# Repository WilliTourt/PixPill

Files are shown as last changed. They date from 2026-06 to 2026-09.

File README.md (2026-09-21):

# 💊 PixPill

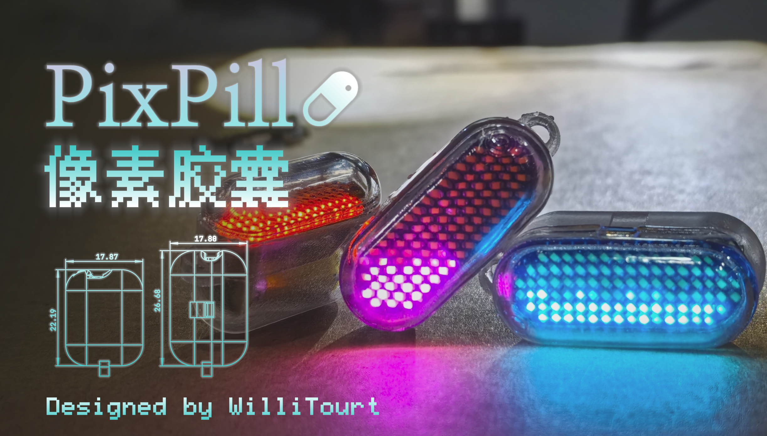
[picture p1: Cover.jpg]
Cover


> A pill-sized LED trinket — with sand and liquid flowing inside. Shake it, tilt it, watch it flow.

> [ENGLISH](README.md) | [中文](README-zh-CN.md)

**PixPill** is a tiny glowing gadget barely larger than a real pill capsule. On a 4-layer HDI micro PCB, it packs an STM32C011 MCU, a BMA530 accelerometer, an IS31FL3736 LED matrix driver, 96× micro LEDs, and an nPM1100 PMIC. The firmware runs physics-based particle simulations — tilt it and sand pours, liquid flows.

Bilibili video link：[Click here](https://www.bilibili.com/video/BV1YWhq6gEwE)

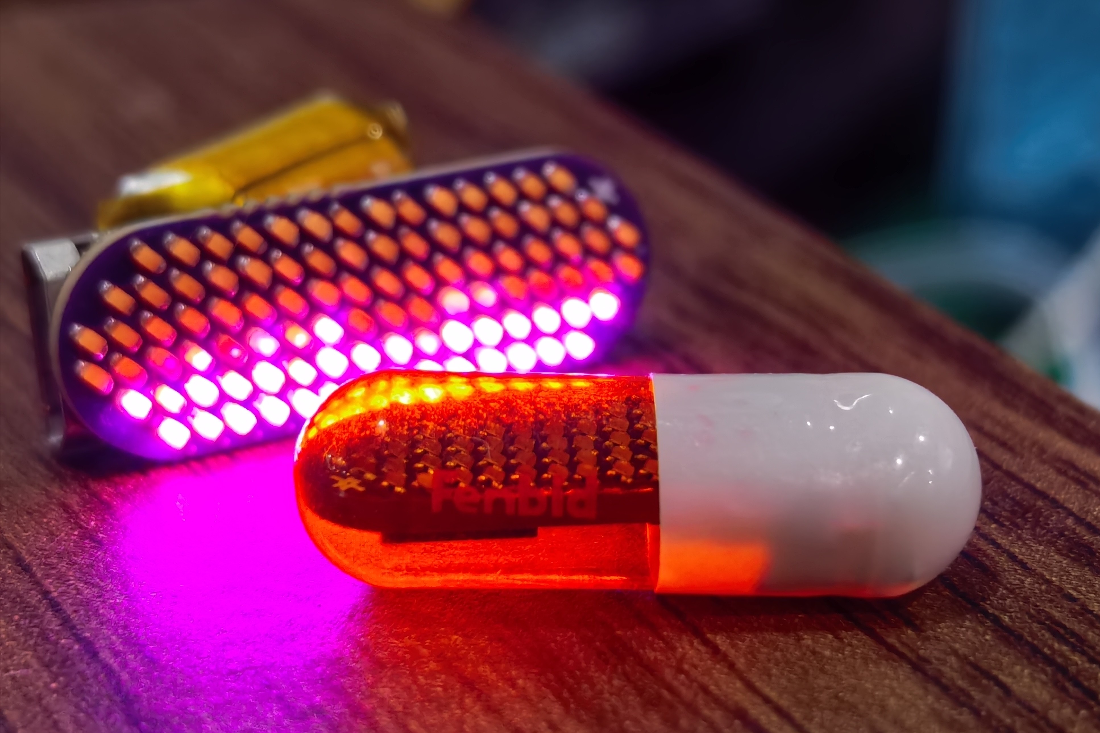
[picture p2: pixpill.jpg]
PixPill in Fenbid Capsule


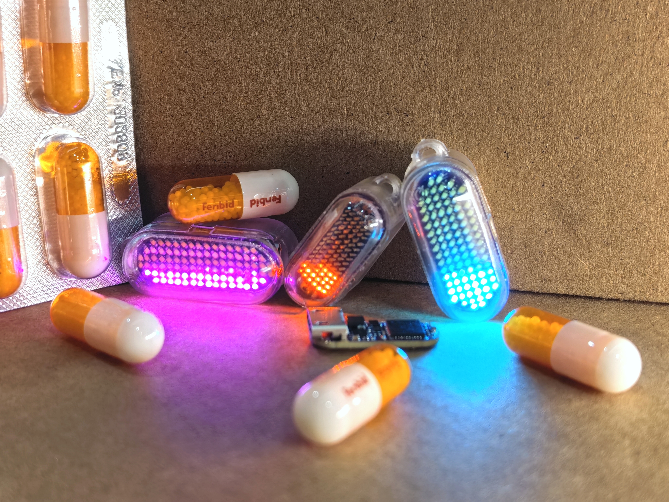
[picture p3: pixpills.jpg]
PixPills


Its tiny PCB dimensions (23.9×8.6 mm / 19.5×6.9 mm) are deliberately aligned with standardized size 000 (26.1×8.5 mm) and size 1 (19.4×6.9 mm) pill capsules.

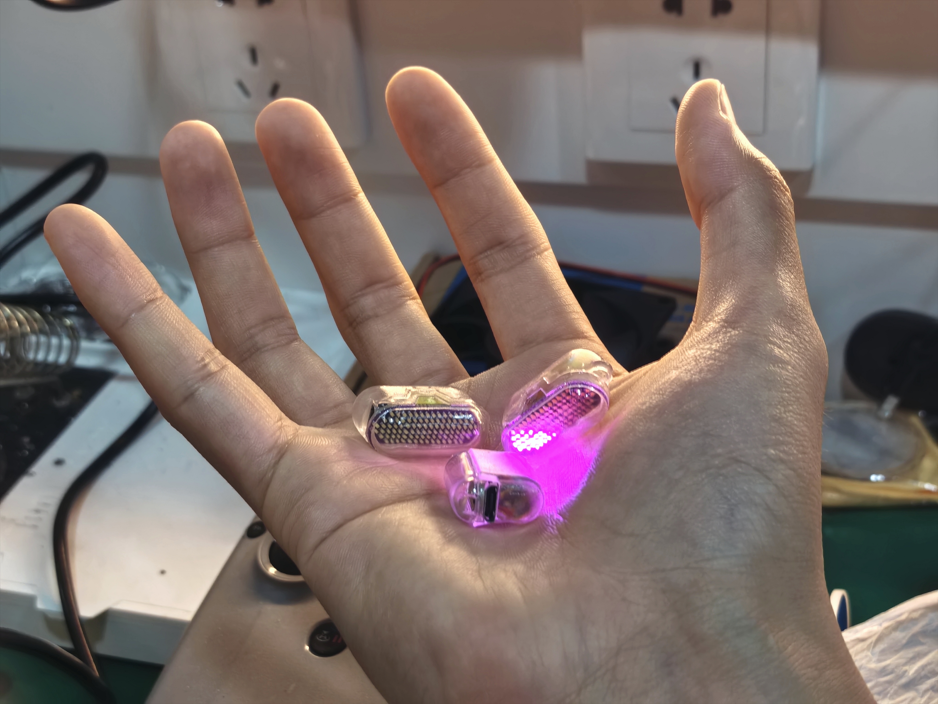
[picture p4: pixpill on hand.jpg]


For detailed hardware design and 3D-related information, see [Hardware Design.md](Hardware/Hardware%20Design.md). For software details, see [Software Design.md](Software/Software%20Design.md).

---

## Features

- **「Tiny」** — PCB as narrow as 6.9 mm in diameter; fits inside a real pill capsule
- **Two physics modes** — Sand (granular, stacks naturally) and Liquid (SPH-inspired fluid with density pressure)
- **Gesture control** — Shake up-down-up-down rapidly to toggle between sand and liquid modes
- **Auto sleep** — Enters nPM1100 ship mode (shutdown) after 22 seconds of stillness to preserve battery
- **USB charging** — microUSB for charging
- **Fault detection** — nPM1100 ERR pin triggers LED array blinking alarm, pausing normal operation
- **Animated transitions** — Boot, shutdown, charging, and error states each have unique LED animations

---

## Hardware

| Component | Part | Notes |
|---|---|---|
| **MCU** | STM32C011D6Y6TR | Cortex-M0+ @ 48 MHz, WLCSP12 (1.7×1.42×0.6 mm, 0.35 mm pitch) |
| **IMU** | BMA530 | 3-axis accelerometer, I²C, WLCSP6 (1.2×0.8×0.55 mm³) |
| **LED Driver** | IS31FL3736 | 12×8 LED matrix controller, I²C paged register access, per-LED 8-bit PWM, 5×5 QFN |
| **LEDs** | 96× 0402 (000#) / 90× 0201 (1#) | Arranged in a pill-shaped layout |
| **PMIC** | nPM1100 | Li-Po charger, max 400 mA LDO, with ship mode |
| **Battery** | 08120 3.7V Li-Po | Charged via microUSB |
| **PCB** | 4-layer 1st-order HDI | 23.9×8.6 mm / 19.5×6.9 mm |

---

## Simulation

### Sand Mode

- Based on a cellular-automaton classic falling-sand algorithm
- 8 gravity directions, conforming to the natural angle of repose of sand
- Particles stack naturally along gravity; tilt spills them
- Frame rate adapts to tilt angle

### Liquid Mode

- SPH-inspired implementation: gravity + density field pressure + inter-particle repulsion + velocity damping
- Finer sub-step integration per frame
- Inter-particle collision detection
- 18×6 density grid mapped to the 96-LED pill-shaped layout
- Surface tension available but currently disabled

---

## Firmware Architecture

```
main.c                   ← STM32CubeMX HAL init → cpp_main() main loop
Components/
├── Src/
│   ├── cpp_main.cpp     ← state machine, gesture detection, main loop
│   ├── bma530.cpp       ← BMA530 I²C driver
│   ├── is31fl3736.cpp   ← IS31FL3736 I²C driver
│   ├── sandsim.cpp      ← sand particle simulation
│   ├── liquidsim.cpp    ← liquid particle simulation
│   └── pixpill_anim.cpp ← boot / shutdown / charging / error animations
└── Inc/                 ← headers + various constexpr LUTs
```

- **No RTOS** — bare-metal superloop
- **State machine:** `BOOT → RUNNING → SHUTDOWN`
- **Compiler:** `arm-none-eabi-g++` (**-Os**)
- **Desktop simulators:** `sand_visual_sim.py` / `liquid_visual_sim.py` — tune particle parameters directly on PC before flashing

Pre-built firmware is also provided; flash directly via STM32 CubeProgrammer or similar tools, via SWD.

### Prerequisites

- `arm-none-eabi-gcc` toolchain, GNU Make
- VSCode + EIDE
- STM32CubeMX (v6.14+) for `.ioc` generation
- STM32CubeProgrammer CLI for flashing

---

## Usage

- **First-time after soldering the battery, plug in USB** → device wakes from ship mode (charging animation plays)

1. **Press the button** → array lights up briefly, boot animation plays, then simulation starts (default: liquid mode)
2. **Tilt** → particles flow with gravity
3. **Shake up-down rapidly 4 times** → toggles between sand and liquid (the detection window is short to avoid interfering with normal handling — shake quickly to switch)
4. **Leave still for 22 seconds** → shutdown animation → enters ship mode

### Status Indicators

- **Array blinks "ERR" 6 times at boot** → IS31FL3736 detected an LED open or short circuit
- **Back LED fast blink (100 ms) & array shows "ERR"** → nPM1100 fault (ERR pin active)
- **Back LED breathing & array shows battery icon for 4 seconds** → USB charging plugged in

---

## Credits

- **PCB:** Designed in EasyEDA Professional, fabricated as 4-layer HDI
- **Simulation algorithm references:**
  - Website: [Falling Sand Simulation — Kyle W. Pfeiffer](https://www.kylepfeiffer.com/projects/4_project/)
  - Website: [Falling Sand](https://jason.today/falling-sand)
  - Website: [Improved Falling Sand](https://jason.today/falling-improved)
  - Repo: [CH32V203Dev — fluid_HXY](https://github.com/PinkiePie1/CH32V203Dev/tree/master/Apps/fluid_HXY)
  - Repo: [embedded-liquid-simulation](https://github.com/SandroMatthias/embedded-liquid-simulation/tree/main/)

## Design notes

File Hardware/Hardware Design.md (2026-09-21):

# PixPill Hardware Design

> Schematics, PCB, BOM, and enclosure assembly guide

> [ENGLISH](Hardware%20Design.md) | [中文](Hardware%20Design_zh-CN.md)

PixPill went through the EVK v1 → EVK v2 → 000# + 1# iterations. From the EVK validation boards to the final capsule-sized designs, the hardware integrates an MCU, IMU, LED driver, 96 micro LEDs, PMIC, and Li-Po battery in an extremely compact space.

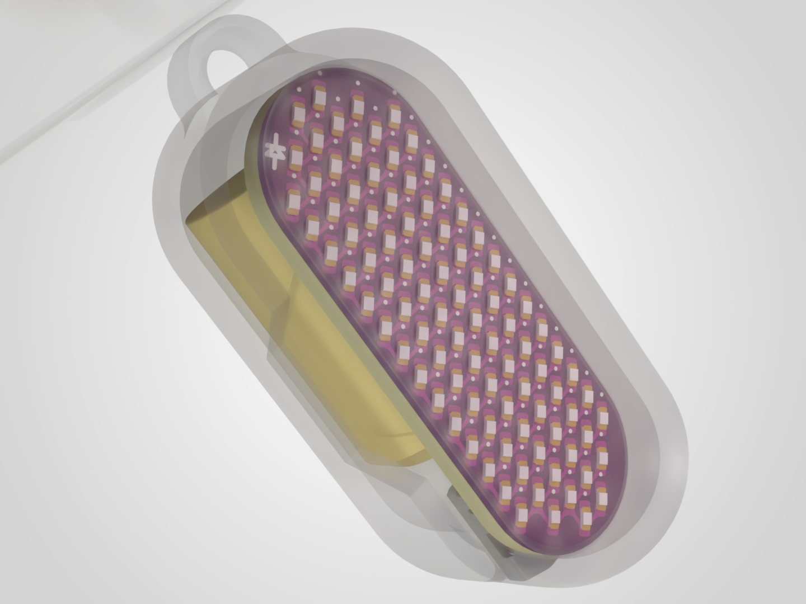
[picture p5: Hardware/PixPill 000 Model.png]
PixPill Model


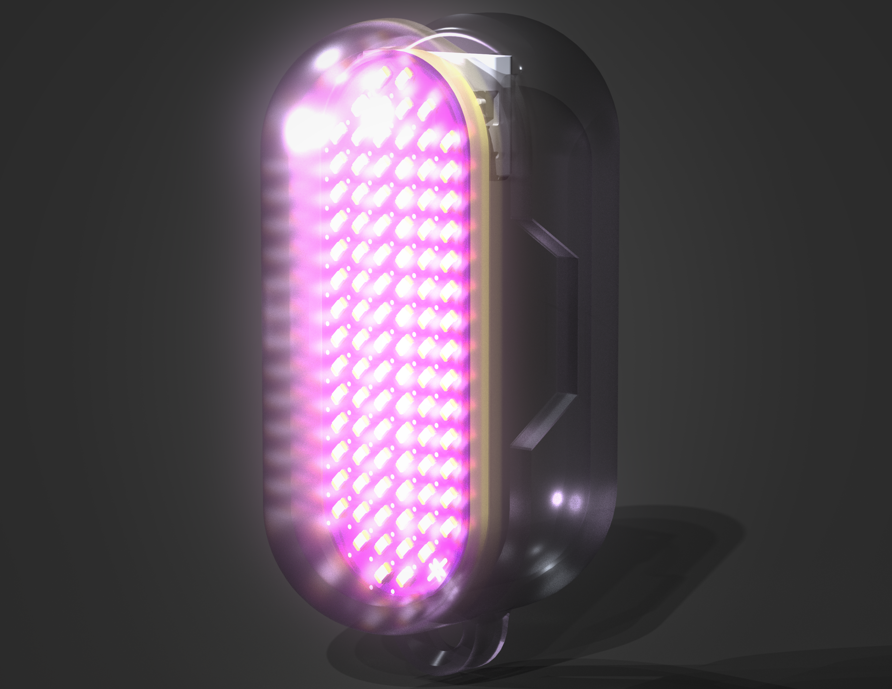
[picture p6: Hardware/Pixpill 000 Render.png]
PixPill Render


---

## Hardware Architecture

```
        ┌──────────────────────────────────────┐
        │              nPM1100                 │
        │  Li-Po Charger + LDO + Ship Mode     │
        │  VOUTB (3.0V) → MCU, IMU, LED Driver │
        └──────┬─────────────────┬─────────────┘
               │ CHG (PB7)       │ ERR (PA8)
        ┌──────▼─────────────────▼─────────────┐
        │           STM32C011D6Y6TR            │
        │          Cortex-M0+ @ 48 MHz         │
        │               WLCSP12                │
        └──┬───────────┬──────────┬────────────┘
           │ I2C1      │ TIM3_CH2 │ SHPACT (PC15)
           │ (SCL:PB6  │ PA7      │ → Ship Mode
           │  SDA:PC14)│          │
       ┌───▼───┐       ▼          ▼
       │       │  LED_STATUS   nPM1100 SHPACT
  ┌────▼────┐  │  (breathing)
  │ BMA530  │  │
  │ IMU     │  │
  │ I2C     │  │
  └─────────┘  │
               │
  ┌────────────▼──────────────┐
  │        IS31FL3736         │
  │  12×8 LED Matrix Driver   │
  │  I2C, per-LED 8-bit PWM   │
  └────────────┬──────────────┘
               │ 96× LED Matrix
     ┌─────────▼───────────┐
     │ 96× 0402 / 90× 0201 │
     │  Pill-shaped layout │
     └─────────────────────┘
```

---

## Schematic Connections

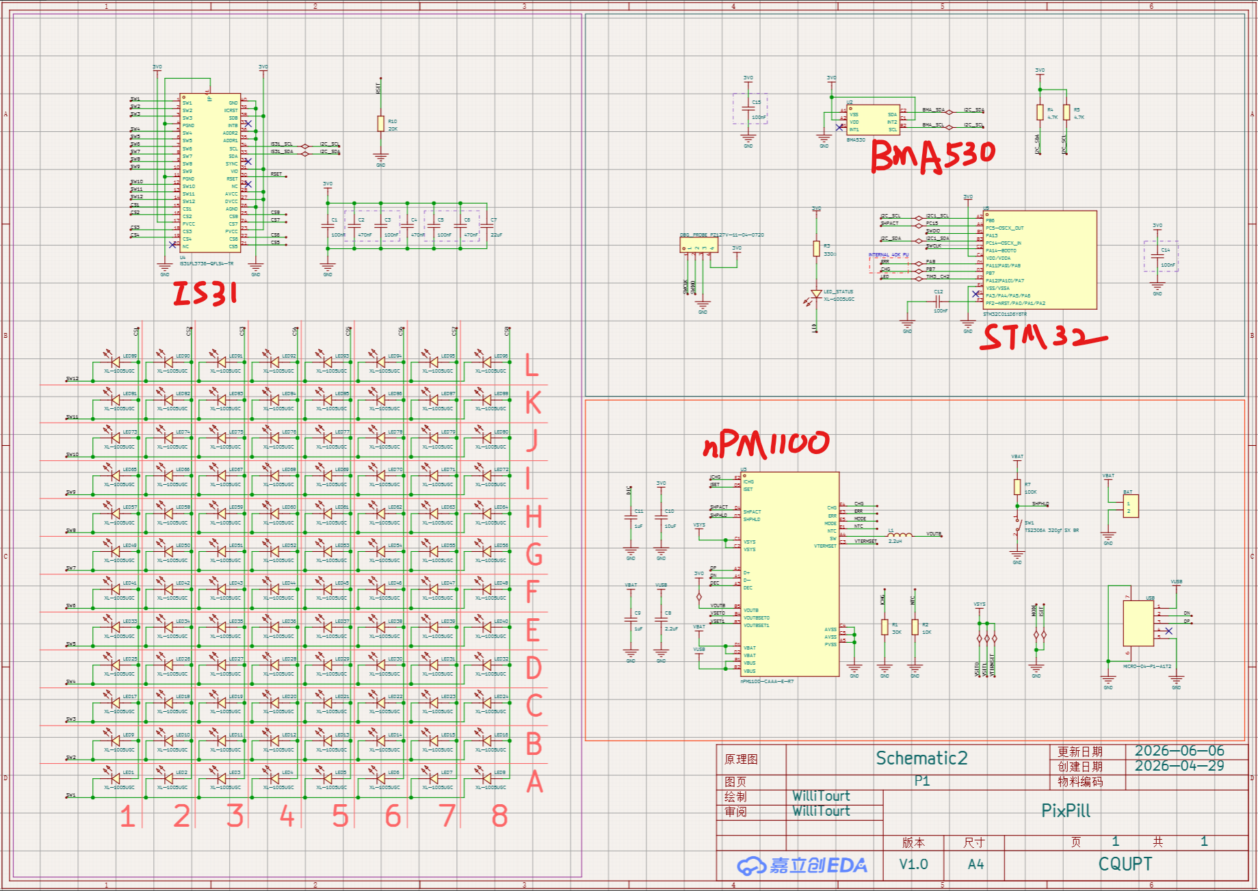
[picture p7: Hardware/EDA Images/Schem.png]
Schematic


### MCU and IMU

| MCU Pin | Function | Connected to |
|---|---|---|
| PA7 | TIM3_CH2 (PWM) | LED_STATUS |
| PA8 | GPIO input (pull-up) | nPM1100 ERR |
| PB6 | I2C1_SCL | BMA530 SCL + IS31FL3736 SCL |
| PC14 | I2C1_SDA | BMA530 SDA + IS31FL3736 SDA |
| PB7 | GPIO input (pull-up) | nPM1100 CHG |
| PC15 | GPIO output | nPM1100 SHPACT (ship-mode control) |

- **BMA530** I2C address: `0x18 << 1`
- **IS31FL3736** I2C address: `0x50 << 1`
- Both devices share the same I2C1 bus.

### Power Management (nPM1100)

- **VBUS** (microUSB) → nPM1100 charging input
- **VOUTB** (3.0 V LDO output) → MCU, BMA530, IS31FL3736, and LED array
- **CHG** → PB7 (charge-status indicator, low = charging)
- **ERR** → PA8 (fault indicator, low = fault)
- **SHPACT** → PC15 (high = enter ship mode and shut down VOUTB)

### IS31FL3736 LED Matrix

- 12×8 matrix driver, with 96 LED positions used in the pill-shaped layout
- I2C paged register addressing (Frames 0–7), with independent 8-bit PWM for each LED
- Initial GCC (global current control) value: 25; adjust it according to battery level and LED brightness

---

## PCB Design

| 000# | 1# |
| --- | --- |
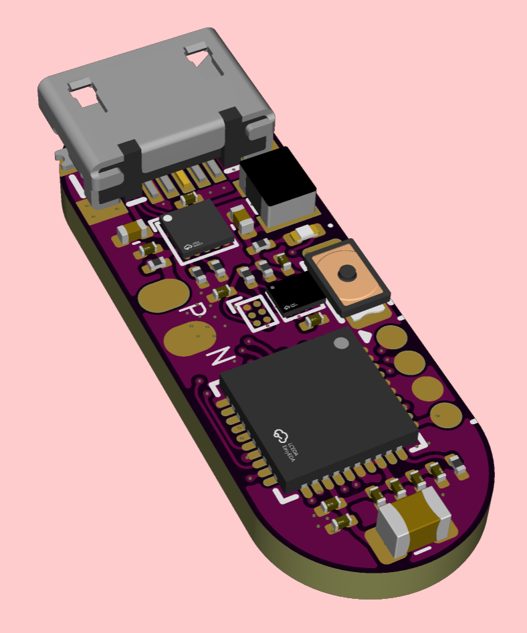
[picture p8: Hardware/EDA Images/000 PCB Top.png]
Top of 000#
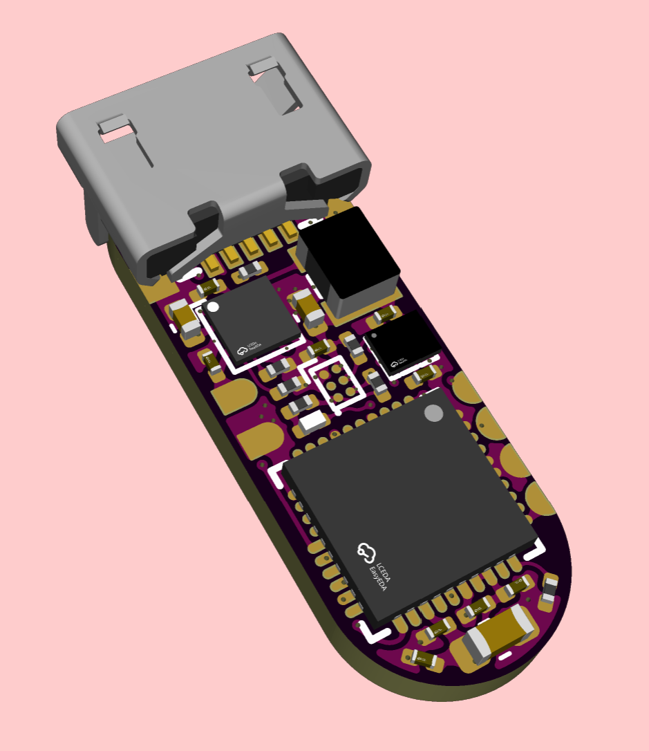
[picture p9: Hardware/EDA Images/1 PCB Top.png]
Top of 1#
|  |  |
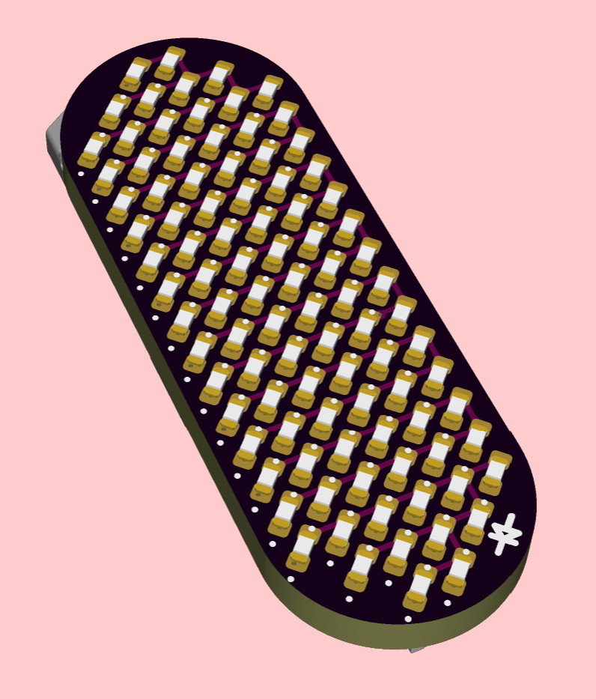
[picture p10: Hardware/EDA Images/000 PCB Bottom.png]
Bottom of 000#
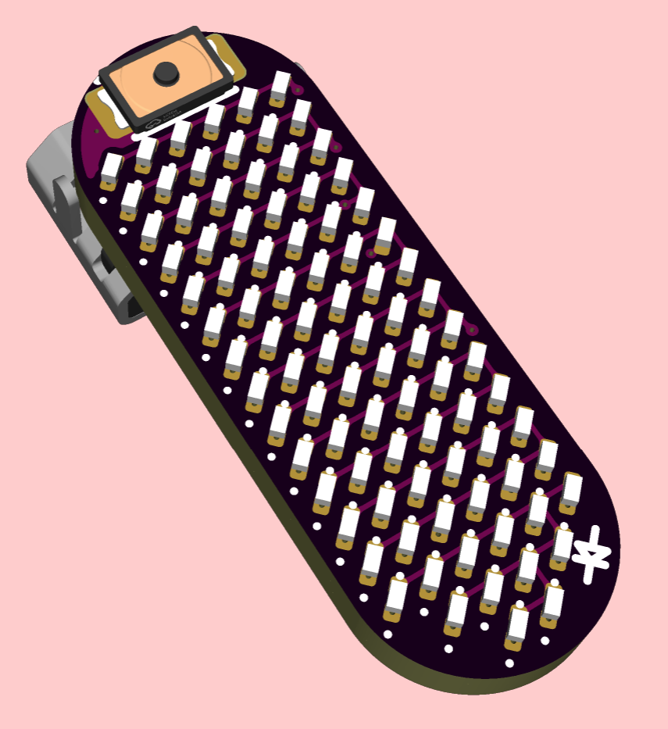
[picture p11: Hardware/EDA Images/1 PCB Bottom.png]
Bottom of 1#
|  |  |

### Process Parameters

| Parameter | Value |
|---|---|
| Layers | 4-layer, 1st-order HDI |
| Board thickness | 1.2 mm |
| Minimum trace/space | 2.7 mil |
| Minimum hole size | 0.1 mm (laser blind microvia) / 0.25 mm (mechanical through-hole) |
| Surface finish | OSP, via-in-pad, plated cap |
| Solder mask color | Purple |

### Stackup

| L4 | L3 | L2 | L1 |
| --- | --- | --- | --- |
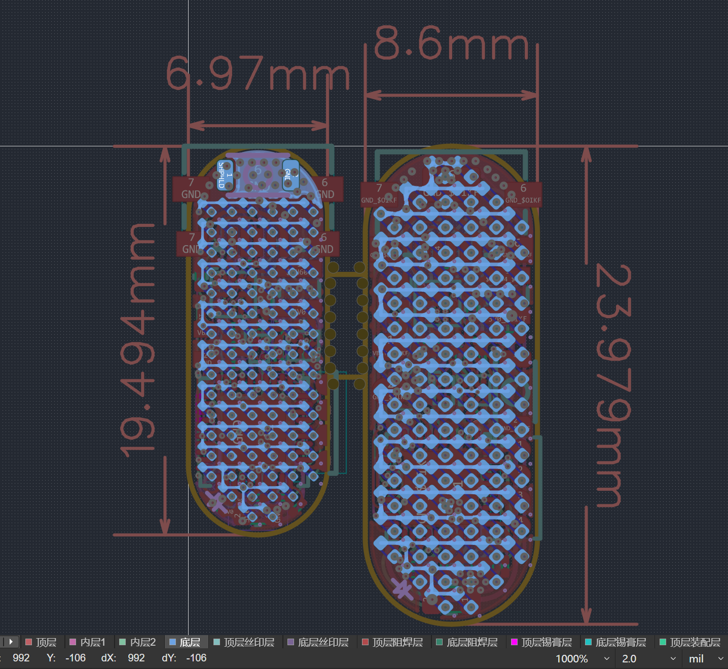
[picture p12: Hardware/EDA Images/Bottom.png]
Bottom
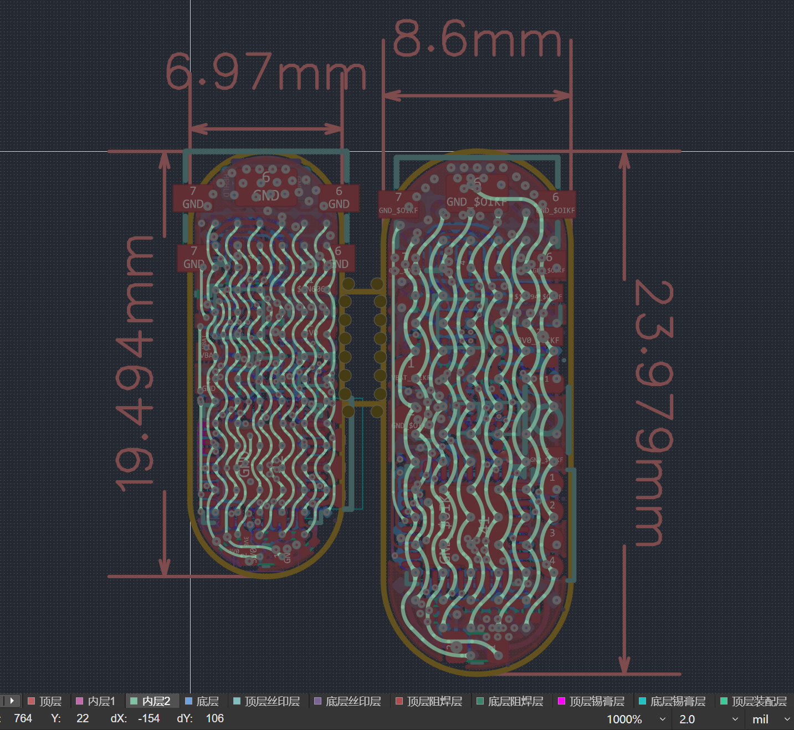
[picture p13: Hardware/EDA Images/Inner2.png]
Inner2
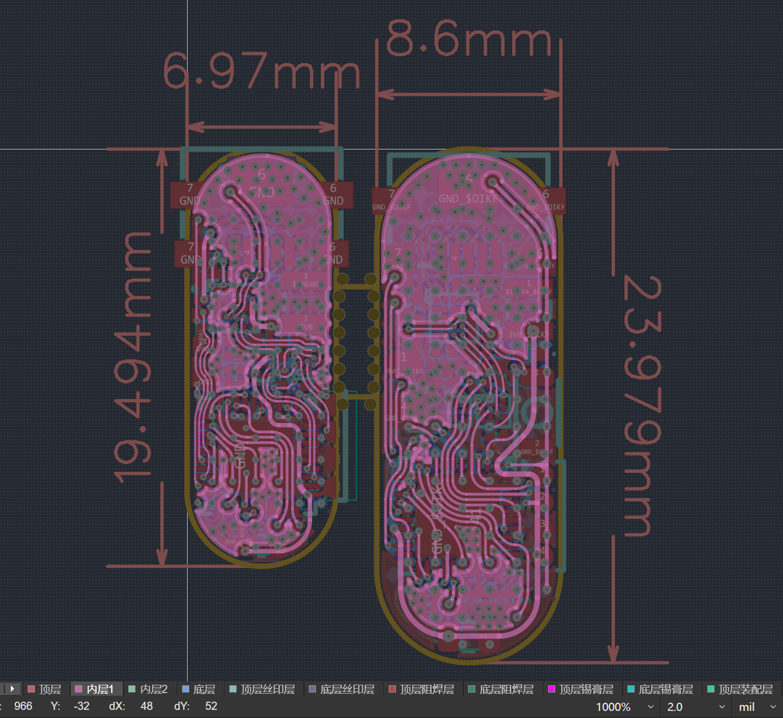
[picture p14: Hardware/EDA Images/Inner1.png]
Inner1
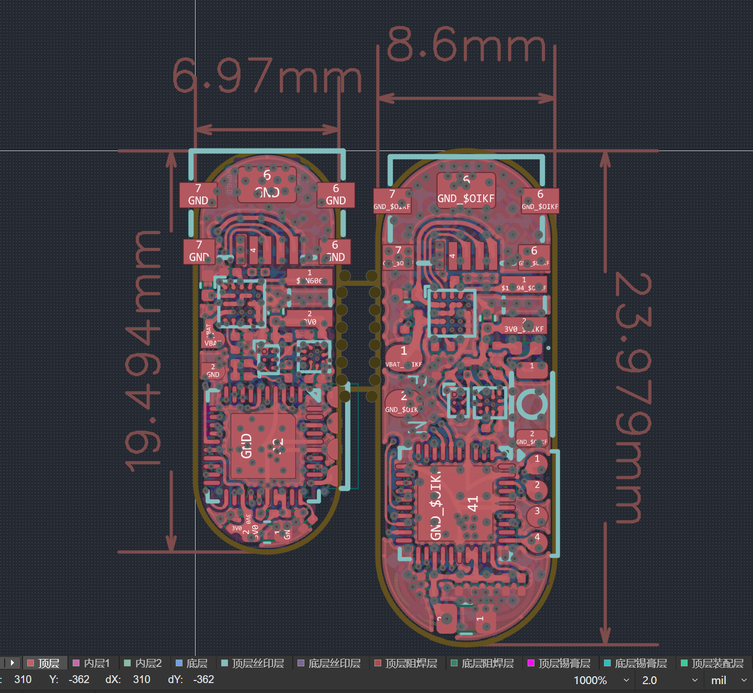
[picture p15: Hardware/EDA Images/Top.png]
Top
|  |  |  |  |

| Layer | Purpose |
|---|---|
| **Top (L1)** | MCU (WLCSP12), BMA530 (WLCSP6), IS31FL3736 (QFN), battery pads, SWD, USB, and GND |
| **Inner1 (L2)** | Signals, power, and GND |
| **Inner2 (L3)** | LED SW/CS signals |
| **Bottom (L4)** | LED array |

- L1→L2 uses laser blind microvias, L2→L3 uses buried vias, and L3→L4 uses blind vias.
- Some WLCSP pads use via-in-pad laser microvias.

### LED Array Layout

The pill-shaped 96 (000#) / 90 (1#) LED layout is arranged from top to bottom as follows:

```
   000# (0402) LED:                     1# (0201) LED:
       ○ ○          Row 0                 ┌─────┐        Row 0–1 Button
     ○ ○ ○ ○        Row 1                 └─────┘
   ○ ○ ○ ○ ○ ○      Rows 2–15           ○ ○ ○ ○ ○ ○      Rows 2–15
   ○ ○ ○ ○ ○ ○                          ○ ○ ○ ○ ○ ○
   ○ ○ ○ ○ ○ ○      (full rows)         ○ ○ ○ ○ ○ ○      (full rows)
       ...          (12 rows of 6)          ...          (12 rows of 6)
   ○ ○ ○ ○ ○ ○                          ○ ○ ○ ○ ○ ○
     ○ ○ ○ ○        Row 16                ○ ○ ○ ○        Row 16
       ○ ○          Row 17                  ○ ○          Row 17
```

- **000#** uses 96× 0402 LEDs (larger packages, easier to hand-solder).
- **1#** uses 90× 0201 LEDs (extremely small; a microscope and precision soldering are required).

### Cost

Because these are small HDI boards, the PCB cost is **very high**, mainly due to HDI engineering, blind/buried vias, and testing. The quotation below is for 135 EBA panels ordered from JLCPCB: approximately **RMB 11.4 per board**, including shipping. The stencil cost an additional RMB 60.

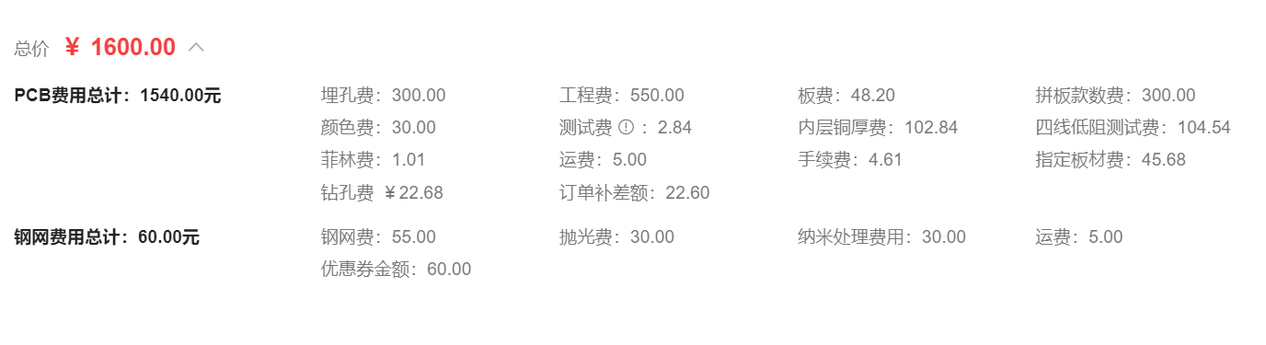
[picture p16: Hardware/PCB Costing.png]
Costing


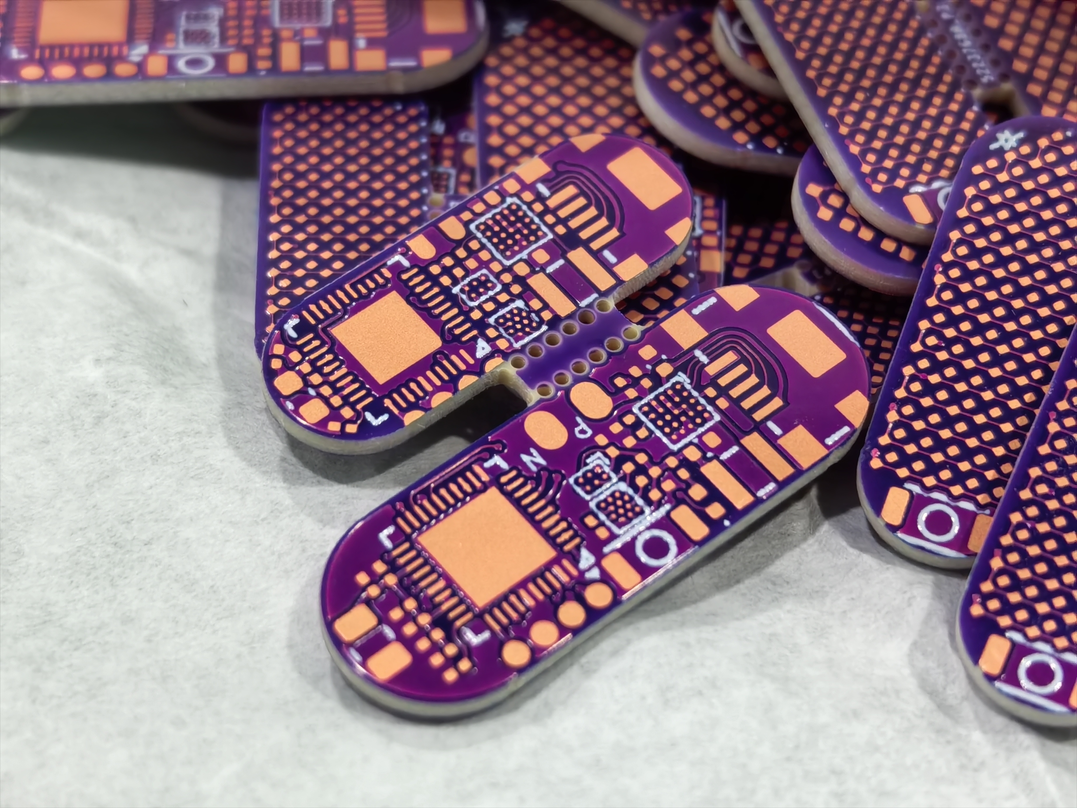
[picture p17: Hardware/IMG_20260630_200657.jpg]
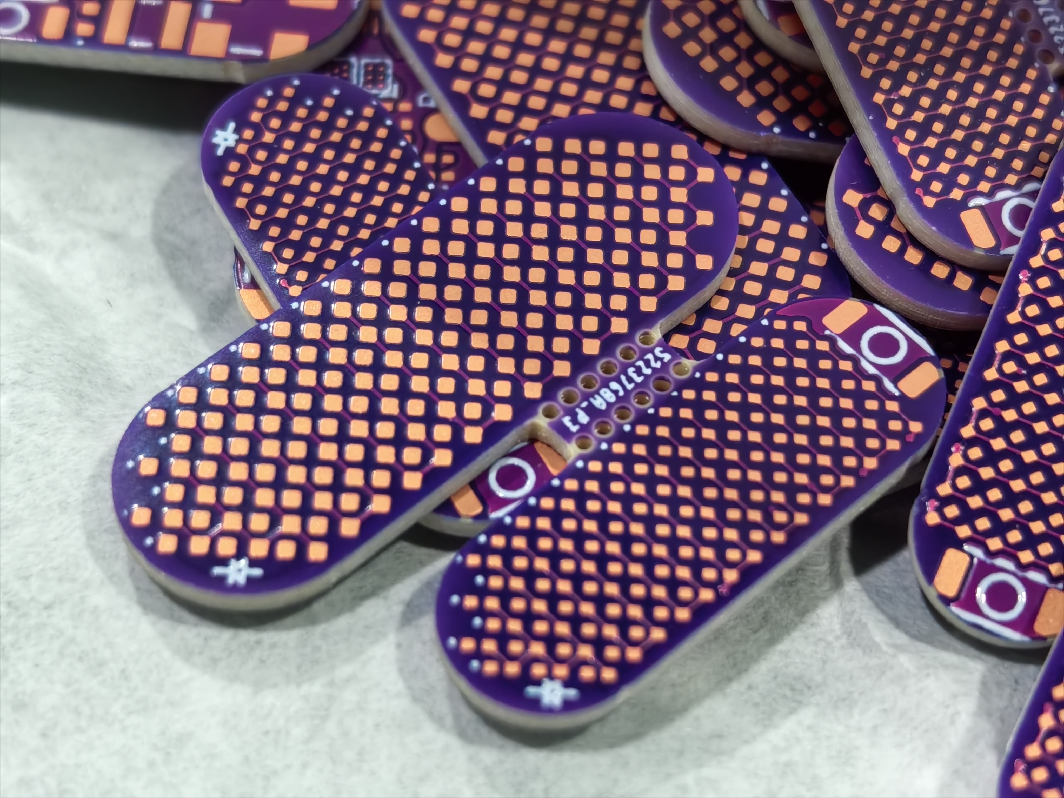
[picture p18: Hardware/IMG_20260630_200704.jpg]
> *Approximately 120 EBA boards are still available (2026.09.15). If you would like to reproduce this project, contact me at (willitourt@foxmail.com). I can provide them at almost the cost price of **RMB 12 per board (~ 1.7 USD/board)**, excluding shipping.*  

### PCB Variants

| Variant | PCB size | LED package | Status |
|---|---|---|---|
| **EVK v1** | 22×22 mm | 0402, 64 LEDs | Deprecated |
| **EVK v2** | 41.979×24 mm | 0201, 96 LEDs | Validation board, producible |
| **000#** | 23.9×8.6 mm | 0402, 96 LEDs | Producible |
| **1#** | 19.5×6.9 mm | 0201, 90 LEDs | Producible |
| **EBA** (Embedded Board Array) | — | — | Producible |

EVK v1/v2 are standard 2-layer boards for firmware development and component validation. 000# and 1# are 4-layer HDI boards reduced to capsule dimensions. EBA is a panel containing 000# and 1# boards.

---

## BOM

See the [PCBs directory](PCBS), which contains `BOM_EVK_V2_TestSchematic_2.xlsx`, `BOM_000# Capsule_Schematic2.xlsx`, and `BOM_7_19 1# Capsule_Schematic1.xlsx`.

Key components:

- **MCU**: STM32C011D6Y6TR WLCSP12
- **IMU**: BMA530 WLCSP6
- **LED driver**: IS31FL3736 QFN (5×5 mm)
- **LEDs**: 96× 0402 (000#) / 90× 0201 (1#)
- **PMIC**: nPM1100-**CAAA-E-R7** WLCSP25

---

## Soldering and Assembly

See the [Assembling Guide](Assembling%20Guide.md) for detailed PCB soldering and enclosure assembly instructions.

---

## 3D Enclosure

All part models are in the [3D Shell directory](3D%20Shell/), provided in SLDPRT, SLDASM, STEP, STL, and 3MF formats.

### Components

| Part | Material | Process |
|---|---|---|
| Main shell | 8001 clear resin / PLA | 3D printing (FDM or SLA; SLA strongly recommended), with optional sanding and polishing |
| Button retainer | General-purpose 3D-printing material | 3D printing (SLA recommended) |
| PCB mounting | — | Directly embedded in the enclosure |

### Assembly Order

See the [Assembling Guide](Assembling%20Guide.md) for the complete assembly order.

---

## Design Files

| File | Format | Description |
|---|---|---|
| Schematics | PNG | Variant subdirectories under `PCBs/Schems and Layout/` |
| PCB layouts | PNG | Top, bottom, and inner layers in the same directories |
| Gerber files | ZIP | Variant- and process-specific files under `PCBs/Gerber/` |
| LCEDA projects | epro2 | `PCBs/EasyEDA(LCEDA) Projects/` |
| 3D enclosure | STEP / STL | `3D Shell/STEP_STL_3MF/` |
| SolidWorks source | SLDASM / SLDPRT | `3D Shell/SW/` |

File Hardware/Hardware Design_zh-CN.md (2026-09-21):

# PixPill 硬件设计

> 原理图、PCB、BOM 与壳体装配指南

> [ENGLISH](Hardware%20Design.md) | [中文](Hardware%20Design_zh-CN.md)

PixPill 经历了 EVK v1 → EVK v2 → 000# + 1# 的迭代过程。从 EVK 验证板到最终胶囊尺寸的设计，硬件方案在极小的空间内集成了 MCU、IMU、LED 驱动、96 颗微型 LED、PMIC 和锂电池。

PixPill Model

PixPill Render

---

## 硬件架构

```
        ┌──────────────────────────────────────┐
        │              nPM1100                 │
        │  Li-Po Charger + LDO + Ship Mode     │
        │  VOUTB (3.0V) → MCU, IMU, LED Driver │
        └──────┬─────────────────┬─────────────┘
               │ CHG (PB7)       │ ERR (PA8)
        ┌──────▼─────────────────▼─────────────┐
        │           STM32C011D6Y6TR            │
        │          Cortex-M0+ @ 48 MHz         │
        │               WLCSP12                │
        └──┬───────────┬──────────┬────────────┘
           │ I2C1      │ TIM3_CH2 │ SHPACT (PC15)
           │ (SCL:PB6  │ PA7      │ → Ship Mode
           │  SDA:PC14)│          │
       ┌───▼───┐       ▼          ▼
       │       │  LED_STATUS   nPM1100 SHPACT
  ┌────▼────┐  │  (breathing)
  │ BMA530  │  │
  │ IMU     │  │
  │ I2C     │  │
  └─────────┘  │
               │
  ┌────────────▼──────────────┐
  │        IS31FL3736         │
  │  12×8 LED Matrix Driver   │
  │  I2C, per-LED 8-bit PWM   │
  └────────────┬──────────────┘
               │ 96× LED Matrix
     ┌─────────▼───────────┐
     │ 96× 0402 / 90× 0201 │
     │  Pill-shaped layout │
     └─────────────────────┘
```

---

## 原理图连接

Schematic

### MCU 与 IMU

| MCU Pin | 功能 | 连接到 |
|---|---|---|
| PA7 | TIM3_CH2 (PWM) | LED_STATUS |
| PA8 | GPIO Input (pull-up) | nPM1100 ERR |
| PB6 | I2C1_SCL | BMA530 SCL + IS31FL3736 SCL |
| PC14 | I2C1_SDA | BMA530 SDA + IS31FL3736 SDA |
| PB7 | GPIO Input (pull-up) | nPM1100 CHG |
| PC15 | GPIO Output | nPM1100 SHPACT（船运模式控制） |

- **BMA530** I2C 地址：`0x18 << 1`
- **IS31FL3736** I2C 地址：`0x50 << 1`
- 两者挂在同一 I2C1 总线上
 
### 电源管理（nPM1100）

- **VBUS**（microUSB）→ nPM1100 充电输入
- **VOUTB**（3.0V LDO 输出）→ MCU + BMA530 + IS31FL3736 + LED 阵列供电
- **CHG** 引脚 → PB7（充电状态指示，低电平=充电中）
- **ERR** 引脚 → PA8（故障指示，低电平=故障）
- **SHPACT** 引脚 → PC15（高电平=进入船运模式，关闭 VOUTB 断电）

### IS31FL3736 LED 矩阵

- 12×8 矩阵驱动，实际使用 96 个 LED 位置（胶囊形状裁剪）
- I2C 分页寄存器寻址（Frame 0-7），每 LED 独立 8-bit PWM
- GCC（全局电流控制）初始值 25，可根据电池电量和LED亮度调整

---

## PCB 设计

| 000# | 1# |
| --- | --- |
| Top of 000# | Top of 1# |
| Bottom of 000# | Bottom of 1# |

### 工艺参数

| 参数 | 值 |
|---|-----|
| 层数 | 4 层一阶 HDI |
| 板厚 | 1.2 mm |
| 最小线宽/线距 | 2.7 mil |
| 最小孔径 | 0.1 mm（激光盲孔）/ 0.25 mm（机械通孔） |
| 表面处理 | OSP，盘中孔工艺，电镀盖帽 |
| 阻焊颜色 | 紫色 |

### 层叠结构

| L4 | L3 | L2 | L1 |
| --- | --- | --- | --- |
| Bottom | Inner2 | Inner1 | Top |

| 层 | 用途 |
|----|---|
| **Top (L1)** | MCU (WLCSP12)、BMA530 (WLCSP6)、IS31FL3736 (QFN)、电池焊盘、SWD、USB + 地 |
| **Inner1 (L2)** | 信号 + 电源 + 地 |
| **Inner2 (L3)** | LED SW/CS 信号 |
| **Bottom (L4)** | LED 阵列 |

- L1→L2 使用激光盲孔（微孔），L2→L3 使用埋孔，L3→L4 使用盲孔
- 部分WLCSP焊盘为盘中孔（激光盲孔）

### LED 阵列布局

胶囊形状的 96（000#）/ 90（1#）LED 布局，从顶部到底部排列如下图：

```
   000# (0402) LED:                     1# (0201) LED:
       ○ ○          Row 0                 ┌─────┐        Row 0-1 Button
     ○ ○ ○ ○        Row 1                 └─────┘        
   ○ ○ ○ ○ ○ ○      Rows 2-15           ○ ○ ○ ○ ○ ○      Rows 2-15
   ○ ○ ○ ○ ○ ○                          ○ ○ ○ ○ ○ ○
   ○ ○ ○ ○ ○ ○      (full rows)         ○ ○ ○ ○ ○ ○      (full rows)
       ...          (12 rows of 6)          ...          (12 rows of 6)
   ○ ○ ○ ○ ○ ○                          ○ ○ ○ ○ ○ ○
     ○ ○ ○ ○        Row 16                ○ ○ ○ ○        Row 16
       ○ ○          Row 17                  ○ ○          Row 17
```

- **000#** 使用 96× 0402 LED（更大封装，容易手工焊接）
- **1#** 使用 90× 0201 LED（极小封装，需要显微镜和精密焊接）

### 成本

值得一提，由于是小体积HDI，PCB板子成本**非常高**，成本主要来源于HDI工程费用、盲埋孔费用和测试费。下图是我从 JLCPCB 订购 135 块 EBA 拼板的报价，单价约为 **11.4 人民币/块**（含运费）。钢网另算 60 元。

Costing

> *目前我仍保留有约 120 块 EBA 板子 (2026.09.15)，如果你想复刻此项目，可以通过邮箱 (willitourt@foxmail.com) 联系我获取！我将以 **12 人民币/块** 接近成本的价格出售给你。运费自理。* PCB PCB

---

### PCB 变体

| 变体 | PCB 尺寸 | LED 封装 | 状态 |
|---|---|---|---|
| **EVK v1** | 22×22 mm | 0402, 64 LEDs | 已废弃 |
| **EVK v2** | 41.979×24 mm | 0201, 96 LEDs | 验证板，可生产 |
| **000#** | 23.9×8.6 mm | 0402, 96 LEDs | 可生产 |
| **1#** | 19.5×6.9 mm | 0201, 90 LEDs | 可生产 |
| **EBA**(Embedded Board Array) | - | - | 可生产 |

EVK v1/v2 是标准 2 层板，用于固件开发和元件验证。000# 和 1# 为四层 HDI，减小到胶囊尺寸。EBA 为000#和1#的拼板。

---

## BOM

详见 [PCBs 目录](PCBS)，包含 `BOM_EVK_V2_TestSchematic_2.xlsx`，`BOM_000# Capsule_Schematic2.xlsx`，`BOM_7_19 1# Capsule_Schematic1.xlsx`。

主要元器件有：

- **MCU**：STM32C011D6Y6TR WLCSP12
- **IMU**：BMA530 WLCSP6
- **LED 驱动**：IS31FL3736 QFN(5x5mm)
- **LED**：96× 0402（000#）/ 90× 0201（1#）
- **PMIC**：nPM1100-**CAAA-E-R7** WLCSP25

---

## 焊接与装配

详情见 [Assembling Guide_zh-CN.md](Assembling%20Guide_zh-CN.md)。

---

## 3D 壳体

所有零件模型均在 [3D Shell 目录](3D%20Shell/) 下。提供 SLDPRT、SLDASM、STEP、STL、3MF。

### 组成

| 部件 | 材料 | 工艺 |
|---|---|---|
| 外壳主体 | 8001透明树脂 / PLA | 3D 打印（FDM 或 SLA，强烈推荐SLA）（可选的打磨抛光） |
| 按钮固定件 | 通用3D打印耗材 | 3D 打印（推荐SLA） |
| PCB 固定 | - | 直接嵌入壳体内 |

### 装配顺序

详情见 [Assembling Guide_zh-CN.md](Assembling%20Guide_zh-CN.md)。

---

## 设计文件

| 文件 | 格式 | 说明 |
|---|---|---|
| 原理图 | PNG | `PCBs/Schems and Layout/` 下按变体分目录 |
| PCB 图 | PNG | 顶层/底层/内层，同上目录 |
| Gerber 文件 | ZIP | `PCBs/Gerber/` 下按变体和工艺分文件 |
| 立创 EDA 项目 | epro2 | `PCBs/EasyEDA(LCEDA) Projects/` |
| 3D 外壳 | STEP / STL | `3D Shell/STEP_STL_3MF/` |
| SolidWorks 源文件 | SLDASM / SLDPRT | `3D Shell/SW/` |

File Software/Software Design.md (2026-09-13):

# PixPill Software Design

> Firmware architecture, simulation algorithms, gesture recognition, power management, and development guide

> [ENGLISH](Software%20Design.md) | [中文](Software%20Design_zh-CN.md)

---

## Table of Contents

- [Architecture Overview](#architecture-overview)
- [State Machine](#state-machine)
- [Sand Simulation (class SandSim)](#sand-simulation-class-sandsim)
- [Liquid Simulation (class LiquidSim)](#liquid-simulation-class-liquidsim)
- [Animation System (class PixPillAnim)](#animation-system-class-pixpillanim)
- [Gesture Recognition](#gesture-recognition)
- [Power Management](#power-management)
- [LED Open/Short Detection](#led-open-short-detection)
- [Firmware Version Adaptation (Conditional Compilation)](#firmware-version-adaptation-conditional-compilation)
- [Development Environment](#development-environment)
- [Desktop Simulators](#desktop-simulators)

---

## Architecture Overview

PixPill firmware uses a **bare-metal superloop** without an RTOS. The main loop is driven by HAL delays, running particle simulation and gesture detection at a fixed frame rate.

```
main.c → cpp_main()

Components/
├── Src/
│   ├── cpp_main.cpp     ← state machine, gesture detection, main loop (~350 lines)
│   ├── bma530.cpp       ← BMA530 I2C accelerometer driver
│   ├── is31fl3736.cpp   ← IS31FL3736 I2C LED matrix driver (paged register access)
│   ├── sandsim.cpp      ← sand simulation (cellular automaton, 32 particles)
│   ├── liquidsim.cpp    ← liquid simulation (SPH-inspired, 16 particles; kept low for performance on Cortex-M0+)
│   └── pixpill_anim.cpp ← boot / shutdown / charging / error animations
└── Inc/                 ← headers + static lookup tables (constexpr LUTs)
```

### System Resources

| Resource | Usage | Notes |
| --- | --- | --- |
| **RAM** | 2872 B / 6 KB (46.74%) | Includes stack, particle buffers, lookup tables |
| **FLASH** | 32656 B / 32 KB (99.7%) | Extremely compact under -Os optimization; flash usage is nearly full |
| **I2C** | I2C1 (PB6-SCL, PC14-SDA) | Shared by BMA530 (addr 0x18 << 1) + IS31FL3736 (addr 0x50 << 1) |
| **TIM3_CH2** | PA7 — LED_STATUS breathing | 1kHz PWM, sin² 64-step LUT |
| **GPIO** | PA8 (ERR), PB7 (CHG), PC15 (SHPACT) | nPM1100 monitoring & control |

Roughly one third of FLASH is consumed by LUTs. Given the C011's 48 MHz computational ceiling and lack of an FPU, precomputed tables are used extensively to keep the simulation fluent.

---

## State Machine

```
 [Power-on / Ship Mode Wake]
        ↓
      BOOT → Boot animation ("PIXPILL" scrolling text)
        ↓
    RUNNING → Physics simulation (default: liquid mode)
        │ 4 shakes within 620ms  → toggle sand/liquid
        │ Still 22s              → SHUTDOWN
        │ nPM ERR                → fault handling
        │ USB plug-in            → charging indicator 4s then resume
        ↓
   SHUTDOWN → Shutdown animation → SHPACT high → enter ship mode
```

- **State transitions are checked only at the top of the main loop** to prevent accidental jumps
- **ERR state** has the highest priority — immediately pauses simulation, flashes LED array alarm, resumes after ERR clears

---

## Sand Simulation (class SandSim)

Based on the classic **falling-sand cellular automaton** algorithm.

### Key Parameters

| Parameter | Value | Notes |
|---|---|---|
| Particle count | 32 | Moving across 96 LED grid cells with velocity and acceleration |
| Gravity directions | 8 (N/S/E/W + diagonals) | Determined by BMA530 accelerometer gravity sector |
| Scan orders | 4 (down/right/down-right/up-right) | Direction-matched row scanning prevents repeated processing |
| Speed levels | 0–5 | Particles accumulate momentum for faster falling |

### Implementation Details

- **Neighbor table**: 96×8 static LUT storing neighbor indices for all 8 directions per cell — O(1) access
- **Scan table**: Scan order selected based on gravity direction, ensuring correct stacking without penetration
- **Speed mechanism**: Particles accumulate velocity in the falling direction (up to 5 steps); steeper tilt = faster fall
- **Adaptive frame rate**: Higher tilt angle → faster frame rate; still → decelerate

---

## Liquid Simulation (class LiquidSim)

SPH-inspired (Smoothed Particle Hydrodynamics) implementation computing density field pressure and inter-particle forces.

### Key Parameters

| Parameter | Final Value | Notes |
|---|---|---|
| Particle count | 16 | Each particle contributes to multiple LED brightness values |
| SUBSTEPS | 2 | Multiple sub-step integrations per frame for stability |
| GRAVITY | 1.4 | Gravitational acceleration |
| MIN_DIST | 1.24 | Minimum particle distance (collision threshold) |
| DAMPING | 0.88 | Velocity damping coefficient |
| COLLISION_DAMPING | 0.5 | Collision energy loss |
| WALL_STRENGTH | 1.4 | Boundary rebound force |
| THRESHOLD | 95 | Density pressure trigger threshold |
| FORCE | 3.6 | Density pressure coefficient |

### Implementation Details

- **Density field**: 18×6 grid; each particle's density contribution is distributed to 4 nearest cells via **bilinear interpolation**
- **Pressure**: Density above threshold generates outward push, distributing particles more evenly
- **Collision detection**: Repulsive force applied when inter-particle distance < MIN_DIST
- **Boundary handling**: Particles bounce off LED array edges with damping
- **Coordinate system**: BMA530 and LED array are mounted back-to-back; gravity.x/y must be negated

### Parameter Tuning

The desktop tuning script `liquid_visual_sim.py` allows visualization and parameter adjustment on a PC before syncing to C++ firmware. Final values were determined through multiple iterations.

---

## Gesture Recognition

Shake gesture detection via **BMA530 X-axis direction change counting**.

### Algorithm

```
Threshold SHAKE_THRESHOLD = 10000 (~±0.6g)
Window SHAKE_WINDOW_MS = 620 ms
Target = 8 direction flips (i.e., 4 up-down shake cycles)

1. Read accelerometer X-axis raw value each frame
2. Exceeding ±10000 counts as a valid direction signal
3. Direction flip → counter +1
4. 8 flips within 620ms → trigger mode toggle
5. Timeout → reset counter
```

### Design Considerations

- **Short detection window (620ms)**: Prevents false triggers during normal handling
- **High threshold (10000)**: Requires a clear, rapid shake motion
- **X-axis only**: Reduces false positives; up-down shake is most natural

---

## Power Management

### nPM1100 Ship Mode

- **Entry condition**: Still for 22 seconds
- **Idle detection**: Frame-by-frame comparison of BMA530 acceleration delta. Uses `MOTION_DELTA_THRESHOLD=1250` — acceleration delta below threshold in any orientation counts as still
- **Shutdown sequence**: Play shutdown animation → SHPACT high (if not charging, 3.0V VOUTB will be cut, MCU will lose power) → STOP mode

### Charging Detection

- USB plug-in pulls `nPM1100 CHG` pin low
- **Charging animation**: Battery icon + LED_STATUS breathing light, plays for 4 seconds then resumes normal simulation
- **After unplug**: Charging animation ends, normal operation continues

### Fault Detection

- `nPM1100 ERR` pin low → immediately pause simulation
- LED array flashes "ERR" text, LED_STATUS fast blinks (100 ms period)
- After ERR clears → resume simulation
- See [nPM1100_PS_v1.5](/Docs/nPM1100_PS_v1.5.pdf) datasheet for specific ERR causes

---

## Animation System (class PixPillAnim)

| Animation | Description | Mechanism |
|---|---|---|
| **Boot** | "PIXPILL" scrolling text | 6-column sliding window over 42-frame bitmap, ~2.7s |
| **Shutdown** | Full brightness → row-by-row fade out | Rows dim from top to bottom |
| **Charging** | Battery outline steady + breathing fill | 1.5s cycle, batch PWM updates to avoid I2C flicker |
| **Error** | "ERR" full-screen blink | 250ms on/off, PWM set once only |

- Animations are **time-driven** (HAL_GetTick) rather than frame-driven, immune to main loop timing variations
- LED matrix glyphs use 18-bit uint32_t bitmaps (6 columns × 3 uint32_t)
- **LUT optimization**: LED index mapping table generated once at init, then O(1) lookup

---

## LED Open/Short Detection

The IS31FL3736 integrates independent open-circuit and short-circuit detection for each LED, and the firmware runs a full LED detection pass once at startup.

### Detection Flow

| Register | Address | Description |
|---|---|---|
| Open Register | PG0 18h-2Fh | 24 bytes; every even bit (0, 2, 4, 6, ...) corresponds to one LED open-circuit status |
| Short Register | PG0 30h-47h | 24 bytes; every even bit corresponds to one short-circuit status |

Register bit layout is identical to the LED On/Off Register (00h-17h): each SW occupies 2 bytes, and D0/D2/D4/D6 correspond to CS1-CS4 (low address) and CS5-CS8 (high address).

1. Set GCC = 0x01
2. Turn on all LEDs (LEDs that remain off will not refresh the detection data)
3. Set the Configuration Register OSD bit 0 → 1 (write 0x04) to trigger a one-shot detection
4. Wait for at least 2 scan cycles (5 ms)
5. Read the Open/Short registers and decode them into 96 boolean values; true means an error
6. Restore the LEDs to the off state and restore the original GCC

### Result Handling

- If detection succeeds (`valid == true`), scan all 96 LEDs and count open/short faults; skip indices 0–5 on the 1# capsule because they do not physically exist
- If any fault exists, play the ERR animation for 3 seconds and then continue normal operation
- If all are normal, proceed silently into the main loop

---

## Firmware Version Adaptation (Conditional Compilation)

PixPill has two capsule versions (for the 000# and 1# capsule), switched by conditional compilation with `PIXPILL_SIZE_1_CAPSULE`.

### Version Differences

| Parameter | 000# | 1# |
|---|---|----|
| Diameter | 6.6 mm | 8 mm |
| LED count | 96 | 90 |
| Physical button | Rear side, on the same side as other components | Top side occupies row 0-1 (6 LEDs) |

### Switch Method

- Edit [Components/Inc/PIXPILL_VERSION_SELECT.h](Components/Inc/PIXPILL_VERSION_SELECT.h) and uncomment `#define PIXPILL_SIZE_1_CAPSULE`
- Or directly uncomment `-DPIXPILL_SIZE_1_CAPSULE` at Makefile line 116

### Adaptation Details

Principle: keep the 96-index layout unchanged and treat the missing LEDs as "walls".

- `LIQUID_LED_MASK`: on the 1# version, all LEDs in row 0-1 are set to false; liquid particle initialization and density field calculation automatically skip them
- `LED_NEIGHBORS[96][8]`: on the 1# version, neighbors for indices 0-5 in all 8 directions are set to -1 (wall), so sand cannot move into those positions
- `SandSim::init()`: on the 1# version, the random initialization range changes from 0-95 to 6-95
- Animation and liquid simulation do not need changes; `LIQUID_LED_MASK` filters them automatically

The rest of the simulation code (scan tables, particle arrays, animation frames, etc.) remains unchanged.

---

## Development Environment

### Recommended Setup

This project is developed using **VSCode + EIDE plugin**, which is the recommended approach.

- **EIDE (Embedded IDE)**: VSCode extension for embedded development — provides integrated project management, compilation, and flashing
  - Install: Search "EIDE" in the VSCode Extension Marketplace
  - Import project: Open the PixPill folder or the PixPill.code-workspace workspace file
- **STM32CubeMX**: Generate HAL initialization code and `.ioc` project file
- **arm-none-eabi-gcc**: Cross-compilation toolchain
- **ST-LINK / J-Link / DAPLink**: Debug probes

### Build and Flash

**Method 1: EIDE (Recommended)**

In VSCode with the EIDE plugin, click the Build button to compile.

**Method 2: GNU Make**

```bash
cd PixPill
make -j$(nproc)
```

After connecting the debug probe, click the Flash button or use CubeProgrammer to flash.

---

## Desktop Simulators

All particle algorithms can first be validated and tuned in Python desktop simulators before firmware development, avoiding repeated flash-debug cycles.

| Script | Purpose |
|---|---|
| `sand_visual_sim.py` | Sand 8-direction simulation, neighbor table + scan table visualization |
| `liquid_visual_sim.py` | Liquid SPH parameter tuning, density field / PWM dual-window visualization |

Python simulator output maps 1:1 to the C++ firmware LED array. Parameters can be tuned in Python and copied directly into the C++ code.

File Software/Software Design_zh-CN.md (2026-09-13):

# PixPill 软件设计

> 固件架构、模拟算法、手势识别、电源管理与开发指南

> [ENGLISH](Software%20Design.md) | [中文](Software%20Design_zh-CN.md)

---

## 目录

- [架构概览](#架构概览)
- [状态机](#状态机)
- [沙粒模拟（class SandSim）](#沙粒模拟class-sandsim)
- [液体模拟（class LiquidSim）](#液体模拟class-liquidsim)
- [动画系统（class PixPillAnim）](#动画系统class-pixpillanim)
- [手势识别](#手势识别)
- [电源管理](#电源管理)
- [LED 开短路检测](#led-开路短路检测)
- [固件版本适配（条件编译）](#固件版本适配条件编译)
- [开发环境](#开发环境)
- [桌面模拟器](#桌面模拟器)

---

## 架构概览

PixPill 固件采用**裸机循环**，不使用 RTOS。主循环由 HAL 延时驱动，按固定帧率运行粒子模拟、手势检测。

```
main.c → cpp_main()

Components/
├── Src/
│   ├── cpp_main.cpp     ← 状态机、手势检测、主循环 (约 350 行)
│   ├── bma530.cpp       ← BMA530 I²C 加速度计驱动
│   ├── is31fl3736.cpp   ← IS31FL3736 I²C LED 矩阵驱动 (分页寄存器)
│   ├── sandsim.cpp      ← 沙粒模拟 (元胞自动机，32 粒子)
│   ├── liquidsim.cpp    ← 液体模拟 (类 SPH，16 粒子)(粒子较少是为了减少计算量，再多会不够流畅)
│   └── pixpill_anim.cpp ← 开机 / 关机 / 充电 / 故障动画
└── Inc/                 ← 头文件 + 静态查找表 (constexpr LUT)
```

### 系统资源

| 资源 | 占用 | 说明 |
|---|---|---|
| **RAM** | 2872 B / 6 KB (46.74%) | 含栈、粒子缓冲区、查找表 |
| **FLASH** | 32656 B / 32 KB (99.7%) | -Os 优化后极为紧凑，FLASH使用率将近100% |
| **I²C** | I2C1 (PB6-SCL, PC14-SDA) | 挂载 BMA530(地址0x18 << 1) + IS31FL3736(地址0x50 << 1) |
| **TIM3_CH2** | PA7 — LED_STATUS 呼吸灯 | 1kHz PWM, sin平方 64 步查表 |
| **GPIO** | PA8 (ERR), PB7 (CHG), PC15 (SHPACT) | nPM1100 监控与控制 |

FLASH 约有三分之一的空间被LUT占用。在 C011 48MHz 计算速度且无 FPU 的限制下，使用了较多查表以提高液体的模拟流畅性。

---

## 状态机

```
 [上电 / 船运唤醒]
        ↓
      BOOT -> 开机动画（"PIXPILL" 滚动字幕）
        ↓
      RUNNING -> 物理模拟（默认：液体模式）
        | 620ms内摇晃4次  -> 切换沙/液
        | 静止 22s       -> SHUTDOWN
        | nPM ERR       -> 故障处理
        | USB 插入       -> 充电指示 4s 后返回
        ↓
      SHUTDOWN -> 关机动画 -> SHPACT 拉高 -> 进入船运模式
```

- **状态切换仅在主循环入口处判断**，避免中途意外跳转
- **电源 ERR 状态**优先级最高——触发时暂停模拟，LED 阵列闪烁报警，等待 ERR 清除后恢复

---

## 沙粒模拟（class SandSim）

基于经典 **falling-sand 元胞自动机**算法。

### 核心参数

| 参数 | 值 | 说明 |
|---|-----|---|
| 粒子数 | 32 | 在 96 个 LED 格点上移动，带有速度和加速度 |
| 重力方向 | 8（上下左右 + 四角） | 基于 BMA530 加速度计重力方向进行八个重力扇区的判定 |
| 扫描顺序 | 4 种（下/右/右下/右上） | 配合重力方向逐行扫描，避免重复处理 |
| 速度等级 | 0-5 级 | 粒子可积累动量加速下落 |

### 实现

- **邻居表**：96×8 静态查找表，存储每个格点 8 个方向的邻居索引，O(1) 访问
- **扫描表**：根据重力方向选择扫描顺序，保证粒子正确堆叠不穿透
- **速度机制**：粒子在下落方向积累速度（最多 5 步），倾斜角度越大下落越快
- **帧率自适应**：倾斜角度越大帧率越高，静置则减速

---

## 液体模拟（class LiquidSim）

类 SPH 的实现，计算密度场压力和粒子间作用力。

### 核心参数

| 参数 | 最终值 | 说明 |
|---|---|---|
| 粒子数 | 16 | 每个粒子对应多个 LED 亮度 |
| SUBSTEPS | 2 | 每帧多次子步积分可提高稳定性 |
| GRAVITY | 1.4 | 重力加速度 |
| MIN_DIST | 1.24 | 粒子最小距离（碰撞阈值） |
| DAMPING | 0.88 | 速度阻尼系数 |
| COLLISION_DAMPING | 0.5 | 碰撞能量损失 |
| WALL_STRENGTH | 1.4 | 边界反弹力 |
| THRESHOLD | 95 | 密度压力触发阈值 |
| FORCE | 3.6 | 密度压力系数 |

### 实现要点

- **密度场**：18×6 网格，每个粒子的密度贡献用**双线性插值**分配到上下左右 4 个最近格子
- **压力**：密度超过阈值时产生向外推力，推动粒子分布更均匀
- **碰撞检测**：粒子间距离 < MIN_DIST 时施加斥力
- **边界处理**：粒子碰到 LED 阵列边界时反弹，带阻尼
- **坐标处理**：BMA530 加速度计与 LED 阵列背对背安装，gravity.x/y 需取反

### 调参流程

桌面调参脚本 `liquid_visual_sim.py` 可先在 PC 上可视化模拟效果，调好参数再同步到 C++ 固件。参数最终值经过多轮迭代确定。

---

## 手势识别

通过 BMA530 加速度计 **X 轴（上下）方向变化计数**实现摇晃手势检测。

### 逻辑

```
阈值 SHAKE_THRESHOLD = 10000（约 ±0.6g）
窗口 SHAKE_WINDOW_MS = 620 ms
目标次数 = 8 次方向变化（即上下摇晃 4 个来回）

1. 每一帧读取加速度 X 轴原始值
2. 超过 ±10000 视为有效方向信号
3. 方向翻转时计数 +1
4. 若 620ms 内完成 8 次翻转 → 触发模式切换
5. 超时则重置计数
```

- **窗口时间较短（620ms）**：避免正常把玩时误触发
- **阈值较高（10000）**：需要明显、快速的摇晃动作
- **仅使用 X 轴**：减少误触发概率，上下摇晃最自然

---

## 电源管理

### nPM1100 船运模式

- **进入条件**：静止 22 秒
- **静止检测**：逐帧比较 BMA530 加速度变化量。任何姿态下加速度差值低于`MOTION_DELTA_THRESHOLD=1250`即视为静止
- **关机流程**：播放关机动画 -> SHPACT 拉高（此时若未充电，3.0V VOUTB将被关闭，MCU将断电） -> STOP 模式

### 充电检测

- USB 插入时 `nPM1100 CHG` 引脚拉低
- **充电动画**：电池图案 + LED_STATUS 呼吸灯，播放 4 秒后恢复正常模拟
- **拔电后**：充电动画结束，继续正常运行

### 故障检测

- `nPM1100 ERR` 引脚拉低 → 立即停止模拟
- LED 阵列闪烁 "ERR" 字样，LED_STATUS 快闪（100ms 周期）
- ERR 解除后恢复模拟
- ERR 具体原因见[nPM1100_PS_v1.5](/Docs/nPM1100_PS_v1.5.pdf)数据单

---

## 动画系统（class PixPillAnim）

| 动画 | 描述 | 原理 |
|---|---|---|
| **开机** | "PIXPILL" 滚动字幕 | 窗口滑动 42 帧位图，约2.7秒 |
| **关机** | 全亮 → 逐行熄灭 | 从顶部往下一行一行熄灭 |
| **充电** | 电池框常亮 + 填充呼吸 | 1.5 秒周期，PWM 批量更新 |
| **故障** | "ERR" 全屏闪烁 | 250ms on/off，PWM 只设一次 |

- 动画通过**时间驱动**（HAL_GetTick）而非帧率驱动，不受主循环帧数影响
- LED 矩阵使用 18 位 uint32_t 位图描述（6 列 × 3 个 uint32_t）
- **查找表优化**：LED 编号映射表在初始化时生成一次，后续 O(1) 查找

---

## LED 开路/短路检测

IS31FL3736 内置每个 LED 的独立开路/短路检测功能，固件在启动时执行一次全 LED 检测。

### 检测流程

| 寄存器 | 地址 | 说明 |
|---|---|---|
| Open Register | PG0 18h-2Fh | 24 字节，每偶数（0，2，4，6）比特对应一个 LED 开路状态 |
| Short Register | PG0 30h-47h | 24 字节，每偶数比特对应一个短路状态 |

寄存器位布局与 LED On/Off Register（00h-17h）完全一致：每个 SW 占 2 字节，D0/D2/D4/D6 对应 CS1-CS4（低地址）和 CS5-CS8（高地址）。

1. 设置 GCC = 0x01
2. 点亮所有 LED（关闭的 LED 不会刷新检测数据）
3. Configuration Register OSD 位 0 -> 1 (写0x04) 触发单次检测
4. 等待 ≥ 2 个扫描周期（5ms）
5. 读取 Open/Short 寄存器 → 解析为 96 个布尔值，真为错误
6. 恢复 LED 关闭状态和原始 GCC

### 结果处理

- 检测成功后（`valid == true`）→ 遍历 96 个 LED，统计开路/短路数量，1# 胶囊下跳过索引 0-5（物理上不存在）
- 存在故障 → 播放 ERR 动画 3 秒后继续正常运行
- 全部正常 → 静默通过，进入主循环

## 固件版本适配（条件编译）

PixPill 有两个胶囊版本（分别适配000#和1#胶囊），通过条件编译 PIXPILL_SIZE_1_CAPSULE 切换。

### 版本差异

| 参数 | 000# | 1# |
| ---- | ---- | ---- |
| 直径 | 6.6mm | 8mm |
| LED 数量 | 96 | 90 |
| 物理按键 | 背部，和其它元件位于同一面 | 顶部占用 row 0-1（6 颗 LED） |

### 切换方式

- **编辑 Components/Inc/PIXPILL_VERSION_SELECT.h**，解注释 #define PIXPILL_SIZE_1_CAPSULE
- 或者直接在 Makefile 第 116 行解注释 -DPIXPILL_SIZE_1_CAPSULE

### 适配细节

原则：保留 96 索引不变，将不存在的 LED 视为"墙体"。

- `LIQUID_LED_MASK`：1# 下 row 0-1 全部置 false，液体粒子初始化和密度场计算自动跳过
- `LED_NEIGHBORS[96][8]`：1# 下索引 0-5 的 8 个方向邻居全部设为 -1（墙体），沙子无法移动到这些位置
- `SandSim::init()`：1# 下随机范围从 0-95 改为 6-95
- 动画/液体：无需改动，LIQUID_LED_MASK 自动过滤

其余模拟代码（扫描表、粒子数组、动画帧等）完全不变。

## 开发环境

### 推荐配置

本项目使用**VSCode + EIDE 插件**进行开发，这也是推荐的方式。

- **EIDE (Embedded IDE)**：VSCode 嵌入式开发插件，提供项目管理、编译、烧录一体化支持
  - 安装：VSCode 扩展市场搜索 "EIDE"
  - 导入项目：导入 PixPill 文件夹或打开PixPill.code-workspace工作区文件即可
- **STM32CubeMX**：生成 HAL 初始化代码和 `.ioc` 工程文件
- **arm-none-eabi-gcc**：交叉编译工具链
- **ST-LINK / J-Link / DAPLink**：调试烧录器

### 编译烧录

**方式一：EIDE（推荐）**

在 VSCode 中使用 EIDE 插件，点击 Build 按钮即可编译。

**方式二：GNU Make**

```bash
cd PixPill
make -j$(nproc)
```

连接调试器后，点击 Flash 按钮或使用 CubeProgrammer 烧录。

---

## 桌面模拟器

所有粒子算法可以先在 Python 桌面模拟器上验证和调参，避免反复烧录调试。

| 脚本 | 用途 |
|---|---|
| `sand_visual_sim.py` | 沙粒 8 方向模拟，邻居表 + 扫描表可视化 |
| `liquid_visual_sim.py` | 液体 SPH 参数调试，密度场/PWM 双窗口可视化 |

Python 模拟器输出与 C++ 固件的 LED 阵列一一对应，参数可在 Python 端调好后直接复制到 C++ 代码中。

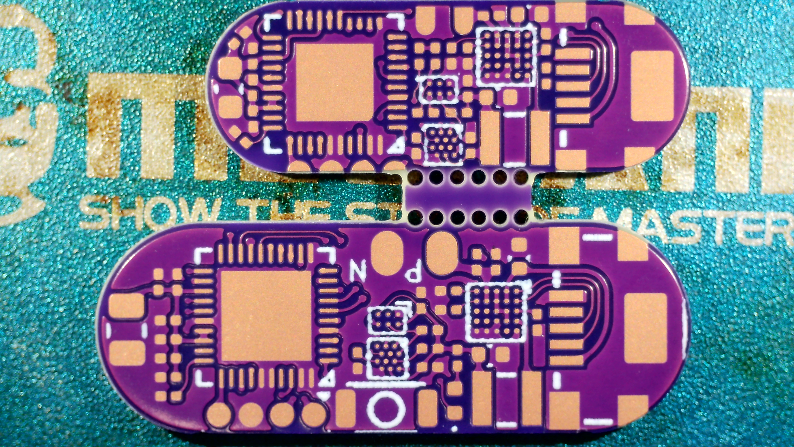
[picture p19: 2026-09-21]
Hardware/PCBs/Imgs/EBA Top.JPG

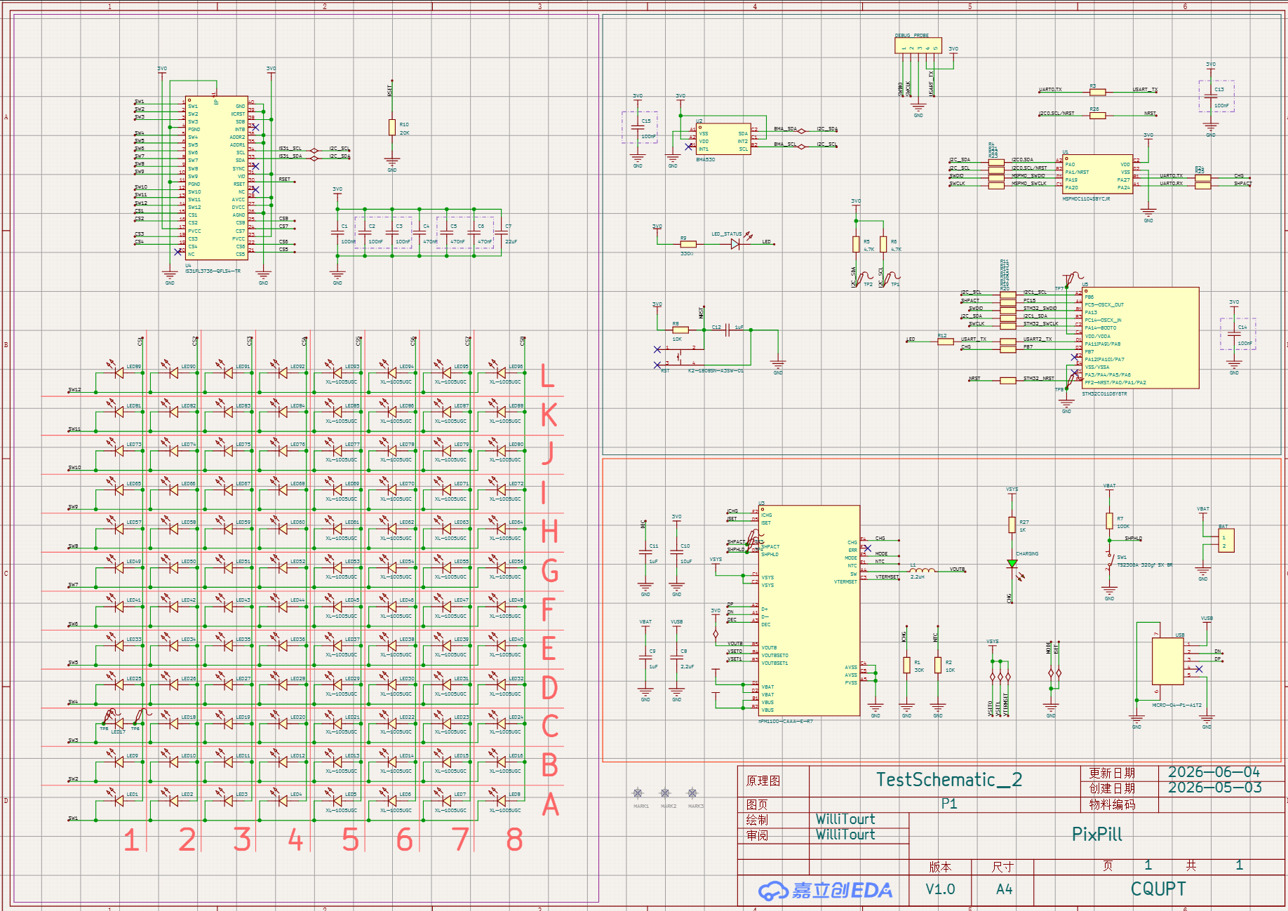
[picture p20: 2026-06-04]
Hardware/PCBs/Schems and Layout/EVK V2/EVK V2 Schematic.png

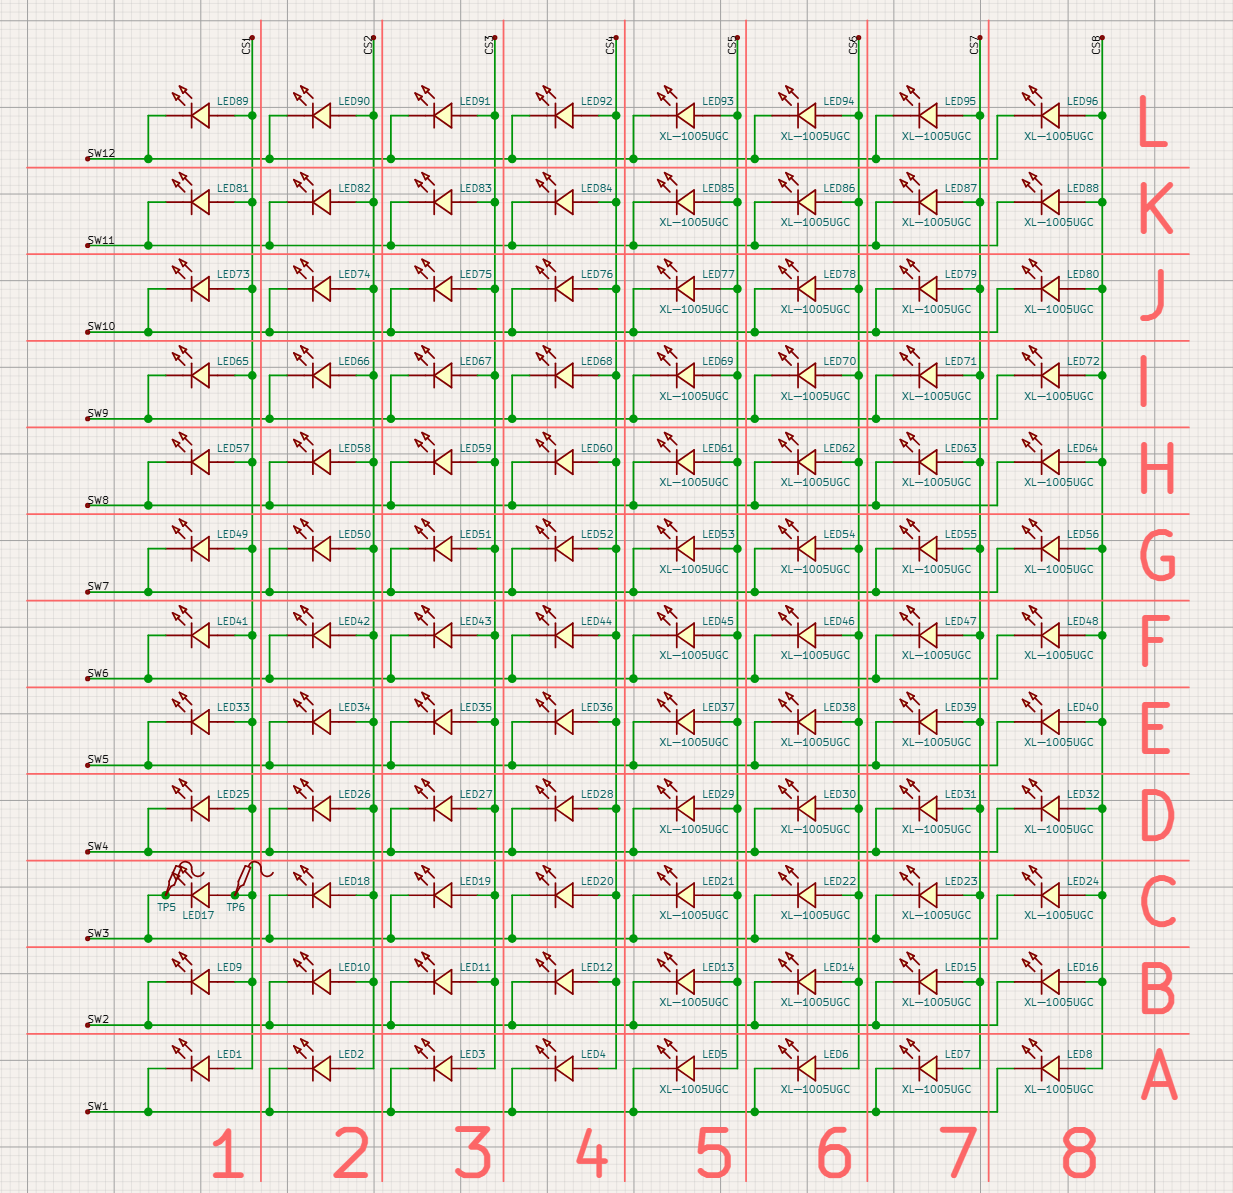
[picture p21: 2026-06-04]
Hardware/PCBs/Schems and Layout/EVK V2/LED Array.png

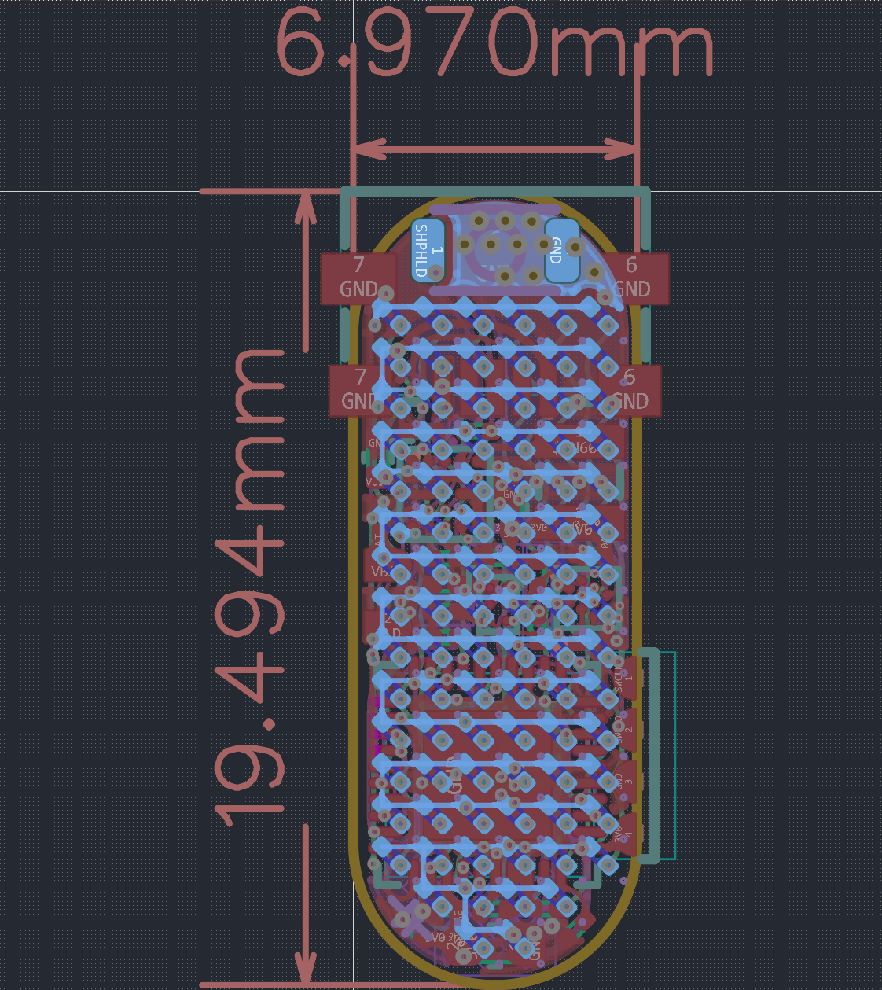
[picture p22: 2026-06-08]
Hardware/PCBs/Schems and Layout/Size 1/Size1 Bottom.png

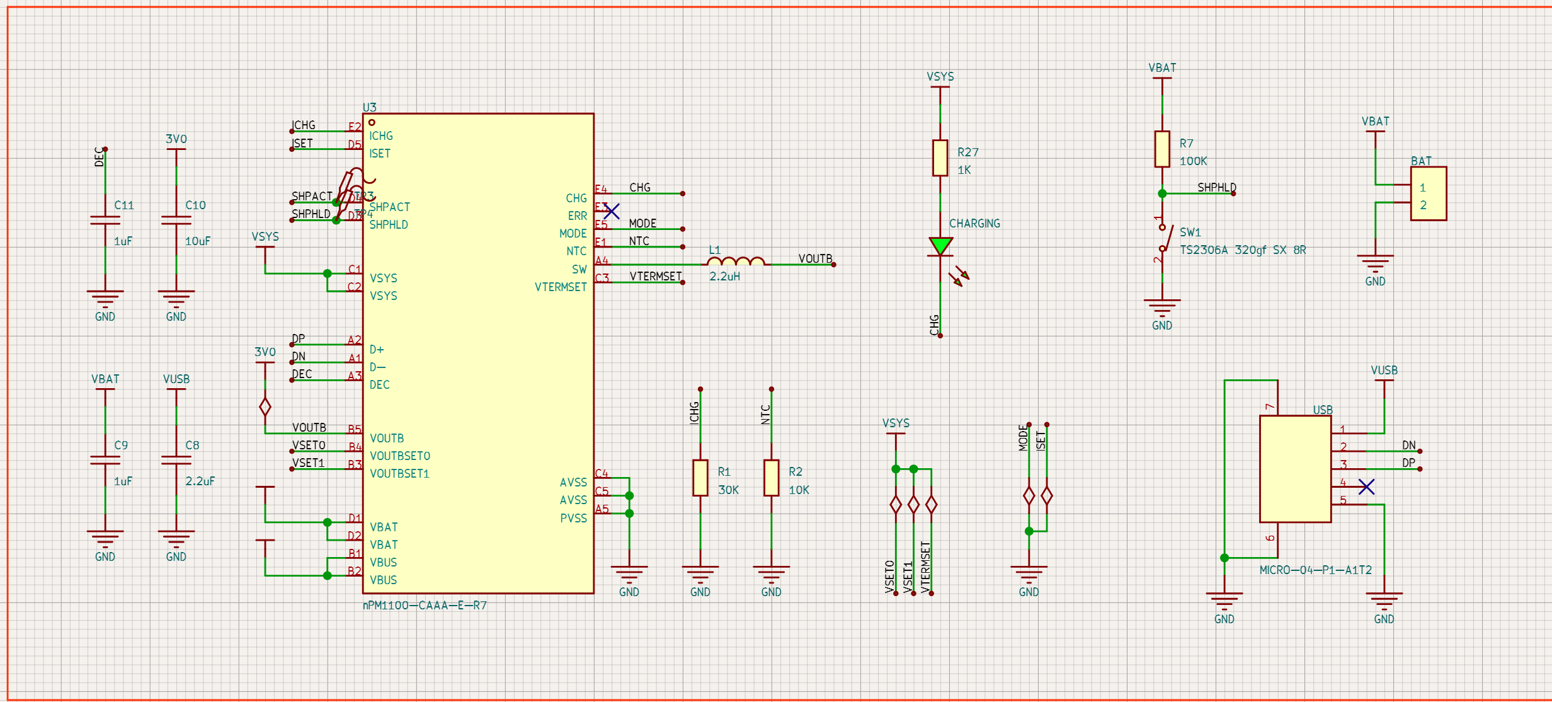
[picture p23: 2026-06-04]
Hardware/PCBs/Schems and Layout/EVK V2/nPM.png

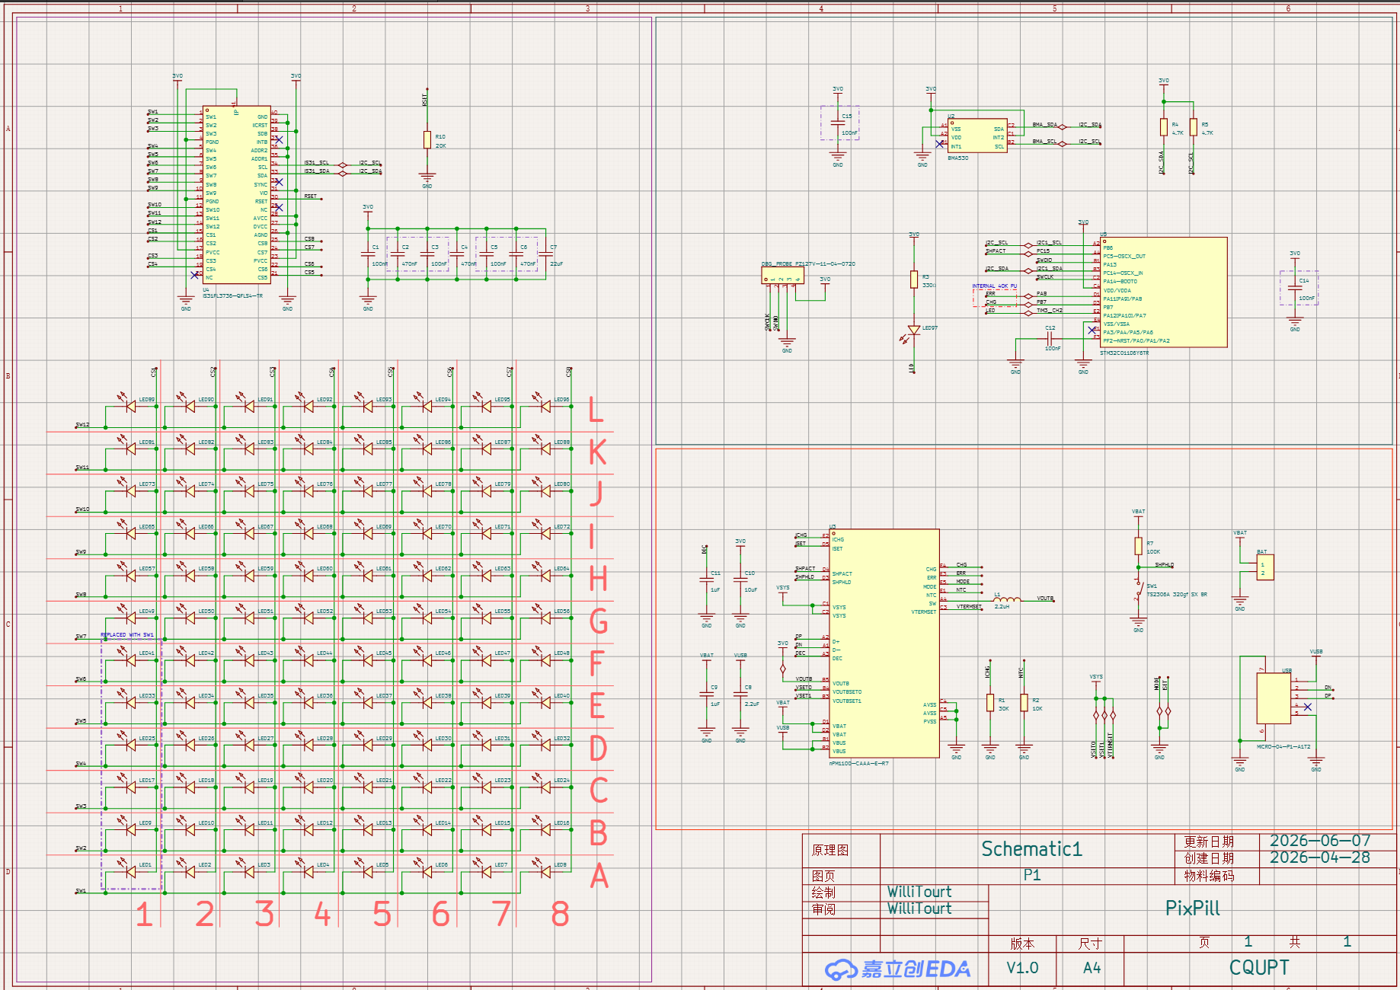
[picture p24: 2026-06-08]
Hardware/PCBs/Schems and Layout/Size 1/Size1 Schematic (3).png

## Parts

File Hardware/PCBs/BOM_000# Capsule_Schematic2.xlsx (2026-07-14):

No. | Quantity | Comment | Designator | Footprint | Value | Manufacturer Part | Manufacturer | Supplier Part | Supplier
1 | 1 | HDR-F_2.54_1x2P | BAT | HDR-TH_2P-P2.54-V-F |  |  |  | C49661
2 | 5 | 100nF | C1,C3,C12,C14,C15 | C_0201_0603Metric | 100nF | GRM033R61E104KE14D | muRata(村田) | C76939 | LCSC
3 | 3 | 470nF | C2,C4,C6 | C_0201_0603Metric | 470nF | GRM033R61E104KE14D | muRata(村田) |  | LCSC
4 | 1 | 100nF | C5 | C_0201_0603Metric | 100nF | GRM033R61E104KE14D | muRata(村田) |  | LCSC
5 | 1 | 22uF | C7 | C_0805_2012Metric | 22uF
6 | 1 | 2.2uF | C8 | C_0402_1005Metric | 2.2uF
7 | 2 | 1uF | C9,C11 | C_0201_0603Metric | 1uF | GRM033R61E104KE14D | muRata(村田) |  | LCSC
8 | 1 | 10uF | C10 | C_0402_1005Metric | 10uF
9 | 1 | PZ127V-11-04-0720 | DBG_PROBE | HDR-TH_4P-P1.27-V-M |  | PZ127V-11-04-0720 | XFCN(兴飞) | C541879 | LCSC
10 | 1 | 2.2uH | L1 | IND-SMD_L2.5-W2.0_MHCHL2520 | 2.2uH | FTC252012S2R2MBCA | cjiang(长江微电) | C5832372 | LCSC
11 | 97 | XL-1005UGC | LED1 to LED96,LED_STATUS | LED_0402_1005Metric |  | XL-1005UGC | XINGLIGHT(成兴光) | C965793 | LCSC
12 | 1 | 30K | R1 | R_0201_0603Metric | 30K | 0201WMF1001TEE | UNI-ROYAL(厚声) |  | LCSC
13 | 1 | 10K | R2 | R_0201_0603Metric | 10K | 0201WMF1001TEE | UNI-ROYAL(厚声) |  | LCSC
14 | 1 | 330Ω | R3 | R_0201_0603Metric | 330Ω | 0201WMF1001TEE | UNI-ROYAL(厚声) |  | LCSC
15 | 2 | 4.7K | R4,R5 | R_0201_0603Metric | 4.7K | 0201WMF1001TEE | UNI-ROYAL(厚声) |  | LCSC
16 | 1 | 100K | R7 | R_0201_0603Metric | 100K | 0201WMF1001TEE | UNI-ROYAL(厚声) |  | LCSC
17 | 1 | 20K | R10 | R_0201_0603Metric | 20K | 0201WMF1001TEE | UNI-ROYAL(厚声) |  | LCSC
18 | 1 | TS2306A 320gf SX 8R | SW1 | SW-SMD_L3.0-W2.0-LS3.5 |  | TS2306A 320gf SX 8R | SHOU HAN(首韩) | C49287209 | LCSC
19 | 1 | BMA530 | U2 | WLCSP-6_L1.2-W0.8-P0.40-TL |  | BMA530 | Bosch(博世) | C23296667 | LCSC
20 | 1 | nPM1100-CAAA-E-R7 | U3 | WLCSP-25_L2.1-W2.1-R5-C5-P0.40-TL-1 |  | nPM1100-CAAA-E-R7 | NORDIC | C5240943 | LCSC
21 | 1 | IS31FL3736-QFLS4-TR | U4 | QFN-40_L5.0-W5.0-P0.40-TL-EP3.6 |  | IS31FL3736-QFLS4-TR | ISSI(美国芯成) | C2678525 | LCSC
22 | 1 | STM32C011D6Y6TR | U5 | WLCSP-12_L1.7-W1.4-P0.35-TL |  | STM32C011D6Y6TR | ST(意法半导体) | C6689571 | LCSC
23 | 1 | MICRO-04-P1-A1T2 | USB | MICRO-USB-SMD_MICRO-04-PX-A1T2 |  | MICRO-04-P1-A1T2 | Yuandi(元迪) | C2682531 | LCSC

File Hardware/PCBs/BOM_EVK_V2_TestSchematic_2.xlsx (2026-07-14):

No. | Quantity | Comment | Designator | Footprint | Value | Manufacturer Part | Manufacturer | Supplier Part | Supplier
1 | 1 | HDR-F_2.54_1x2P | BAT | HDR-TH_2P-P2.54-V-F |  |  |  | C49661
2 | 6 | 100nF | C1,C2,C3,C13,C14,C15 | C0201 | 100nF | GRM033R61E104KE14D | muRata(村田) | C76939 | LCSC
3 | 3 | 470nF | C4,C5,C6 | C0201 | 470nF | GRM033R61E104KE14D | muRata(村田) |  | LCSC
4 | 1 | 22uF | C7 | C_0805_2012Metric | 22uF
5 | 1 | 2.2uF | C8 | C_0402_1005Metric | 2.2uF
6 | 2 | 1uF | C9,C11 | C0201 | 1uF | GRM033R61E104KE14D | muRata(村田) |  | LCSC
7 | 1 | 10uF | C10 | C_0402_1005Metric | 10uF
8 | 1 | 1uF | C12 | C0603 | 1uF
9 | 1 | LED0603-GREEN | CHARGING | LED_0603_1608Metric
10 | 1 | HDR-F_2.54_1x5P | DEBUG_PROBE | HDR-TH_5P-P2.54-V-F |  |  |  | C50950
11 | 1 | 2.2uH | L1 | IND-SMD_L2.5-W2.0_MHCHL2520 | 2.2uH | FTC252012S2R2MBCA | cjiang(长江微电) | C5832372 | LCSC
12 | 48 | XL-0201UOC | LED1,LED2,LED3,LED4,LED9,LED10,LED11,LED12,LED17,LED18,LED19,LED20,LED25,LED26,LED27,LED28,LED33,LED34,LED35,LED36,LED41,LED42,LED43,LED44,LED49,LED50,LED51,LED52,LED57,LED58,LED59,LED60,LED65,LED66,LED67,LED68,LED73,LED74,LED75,LED76,LED81,LED82,LED83,LED84,LED89,LED90,LED91,LED92 | LED-SMD_L0.7-W0.4-RD_IN-S21AT5UW |  | XL-0201UOC | XINGLIGHT(成兴光) | C5440629 | LCSC
13 | 48 | XL-1005UGC | LED5,LED6,LED7,LED8,LED13,LED14,LED15,LED16,LED21,LED22,LED23,LED24,LED29,LED30,LED31,LED32,LED37,LED38,LED39,LED40,LED45,LED46,LED47,LED48,LED53,LED54,LED55,LED56,LED61,LED62,LED63,LED64,LED69,LED70,LED71,LED72,LED77,LED78,LED79,LED80,LED85,LED86,LED87,LED88,LED93,LED94,LED95,LED96 | LED0402-RD_GREEN |  | XL-1005UGC | XINGLIGHT(成兴光) | C965793 | LCSC
14 | 1 | LED0603-WHITE | LED_STATUS | LED_0603_1608Metric
15 | 1 | 30K | R1 | R0201 | 30K | 0201WMF1001TEE | UNI-ROYAL(厚声) |  | LCSC
16 | 1 | 10K | R2 | R0201 | 10K | 0201WMF1001TEE | UNI-ROYAL(厚声) |  | LCSC
17 | 17 | 10K | R3,R4,R11,R12,R13,R14,R15,R16,R17,R19,R20,R21,R22,R23,R24,R25,R26 | R_0402_1005Metric | 10K
18 | 2 | 4.7K | R5,R6 | R_0603_1608Metric | 4.7K
19 | 1 | 100K | R7 | R0201 | 100K | 0201WMF1001TEE | UNI-ROYAL(厚声) |  | LCSC
20 | 1 | 10K | R8 | R0603 | 10K
21 | 1 | 330Ω | R9 | R_0603_1608Metric | 330Ω
22 | 1 | 20K | R10 | R0201 | 20K | 0201WMF1001TEE | UNI-ROYAL(厚声) |  | LCSC
23 | 1 | 1K | R27 | R0603 | 1K
24 | 1 | K2-1808SN-A3SW-01 | RST | SW-SMD_4P-L4.2-W3.3-P2.15-LS5.1 |  | K2-1808SN-A3SW-01 | 韩国韩荣 | C2690012 | LCSC
25 | 1 | TS2306A 320gf SX 8R | SW1 | SW-SMD_L3.0-W2.0-LS3.5 |  | TS2306A 320gf SX 8R | SHOU HAN(首韩) | C49287209 | LCSC
26 | 8 | Test-Point | TP1,TP2,TP3,TP4,TP5,TP6,TP7,TP8 | Test-Point-0.5mm
27 | 1 | MSPM0C1104S8YCJR | U1 | DSBGA-8_L1.6-W0.9-R2-C4-P0.35-TL |  | MSPM0C1104S8YCJR | TI(德州仪器) | C53449704 | LCSC
28 | 1 | BMA530 | U2 | WLCSP-6_L1.2-W0.8-P0.40-TL |  | BMA530 | Bosch(博世) | C23296667 | LCSC
29 | 1 | nPM1100-CAAA-E-R7 | U3 | WLCSP-25_L2.1-W2.1-R5-C5-P0.40-TL-1 |  | nPM1100-CAAA-E-R7 | NORDIC | C5240943 | LCSC
30 | 1 | IS31FL3736-QFLS4-TR | U4 | QFN-40_L5.0-W5.0-P0.40-TL-EP3.6 |  | IS31FL3736-QFLS4-TR | ISSI(美国芯成) | C2678525 | LCSC
31 | 1 | STM32C011D6Y6TR | U5 | WLCSP-12_L1.7-W1.4-P0.35-TL |  | STM32C011D6Y6TR | ST(意法半导体) | C6689571 | LCSC
32 | 1 | MICRO-04-P1-A1T2 | USB | MICRO-USB-SMD_MICRO-04-PX-A1T2 |  | MICRO-04-P1-A1T2 | Yuandi(元迪) | C2682531 | LCSC

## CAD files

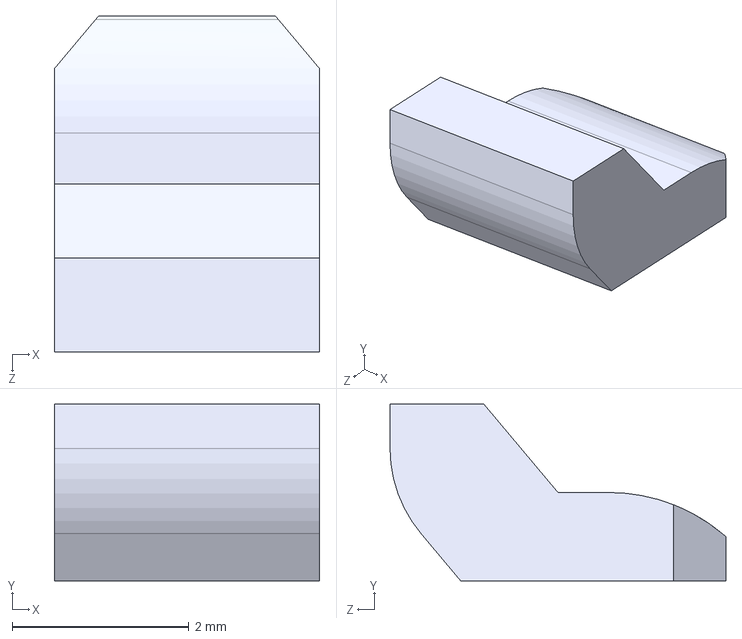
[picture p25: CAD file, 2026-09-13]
Hardware/3D Shell/STEP_STL_3MF/000#/BTN Attacher 000#.STEP
3.00 x 2.00 x 3.80 mm

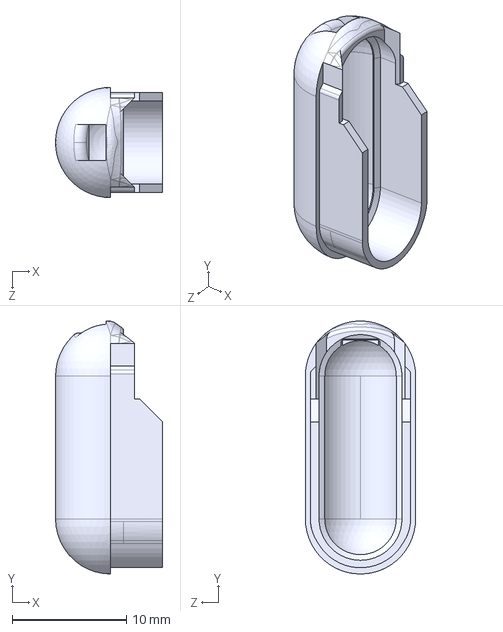
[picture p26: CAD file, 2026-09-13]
Hardware/3D Shell/STEP_STL_3MF/1#/Shell 1#_Male.STEP
9.39 x 22.2 x 9.67 mm

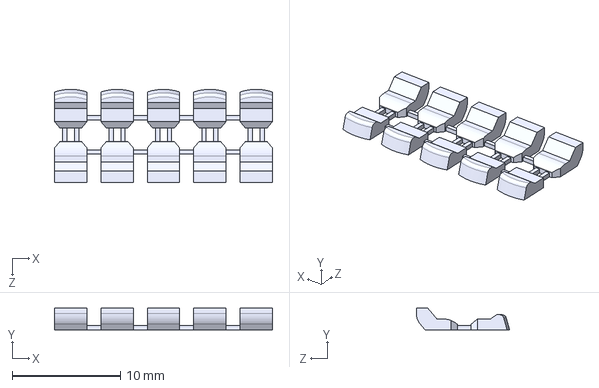
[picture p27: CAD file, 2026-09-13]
Hardware/3D Shell/STEP_STL_3MF/BTN4manufacture-s.STEP
20.1 x 2.00 x 8.62 mm

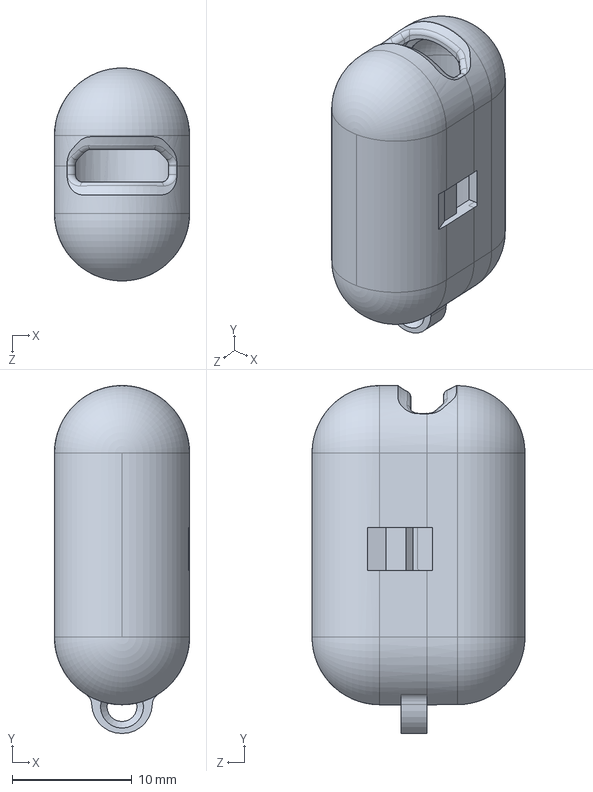
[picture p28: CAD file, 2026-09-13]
Hardware/3D Shell/SW/000#/PixPill Shell 000#.SLDPRT
11.3 x 29.1 x 17.8 mm

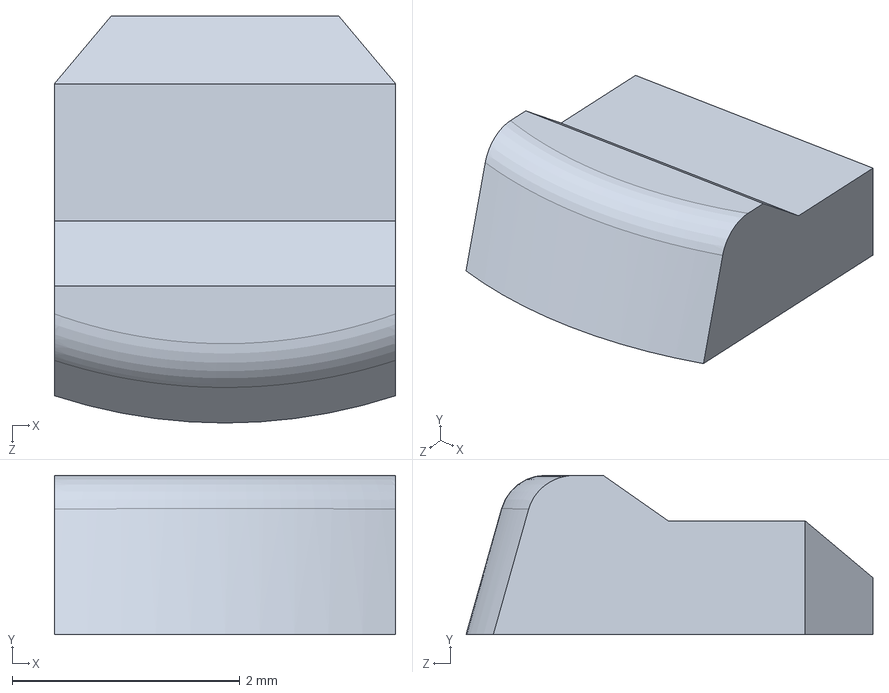
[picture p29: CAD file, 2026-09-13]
Hardware/3D Shell/SW/1#/PixPill BTN Attacher 1#.SLDPRT
3.00 x 1.40 x 3.58 mm

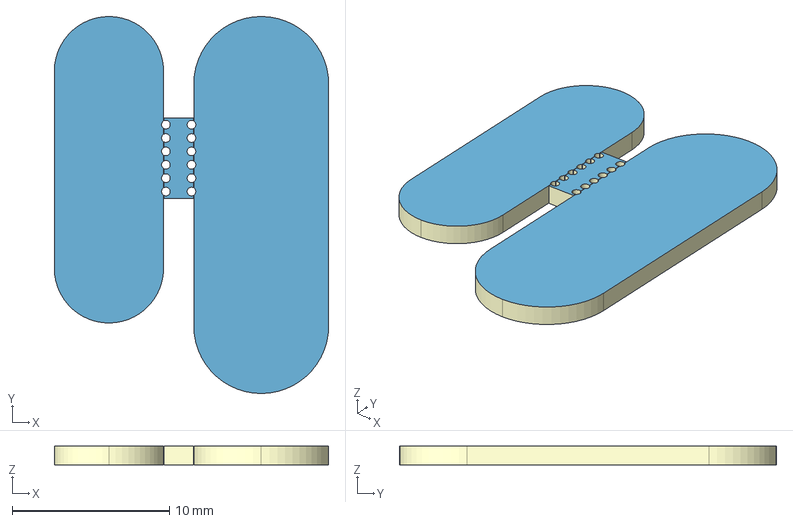
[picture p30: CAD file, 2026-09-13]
Hardware/3D Shell/SW/3D_Embedded Board Array.step
17.4 x 24.0 x 1.20 mm
Board~RZhH
TopCopper~RZhH
BottomCopper~RZhH
TopSilkscreen~RZhH
BottomSilkscreen~RZhH
TopFpcStiffener~RZhH
BottomFpcStiffener~RZhH

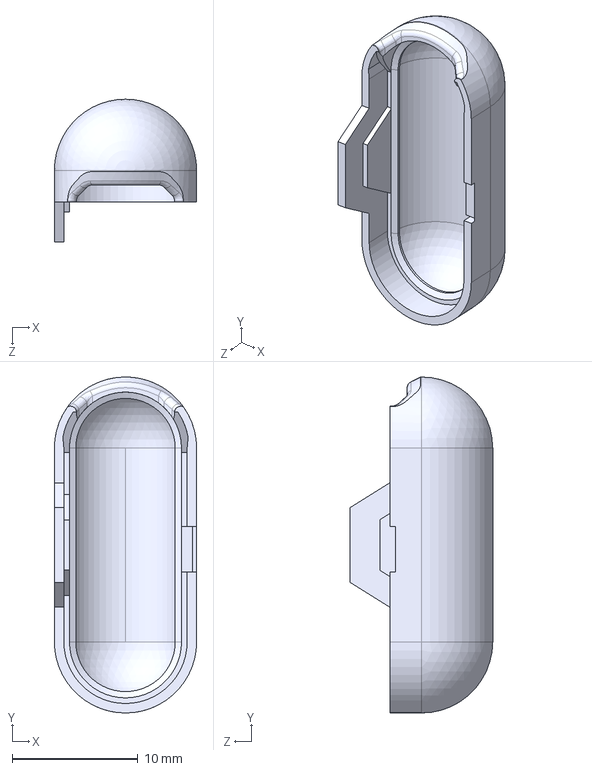
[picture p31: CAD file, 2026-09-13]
Hardware/3D Shell/STEP_STL_3MF/000#/Shell 000#_Female.STEP
11.3 x 26.7 x 11.3 mm

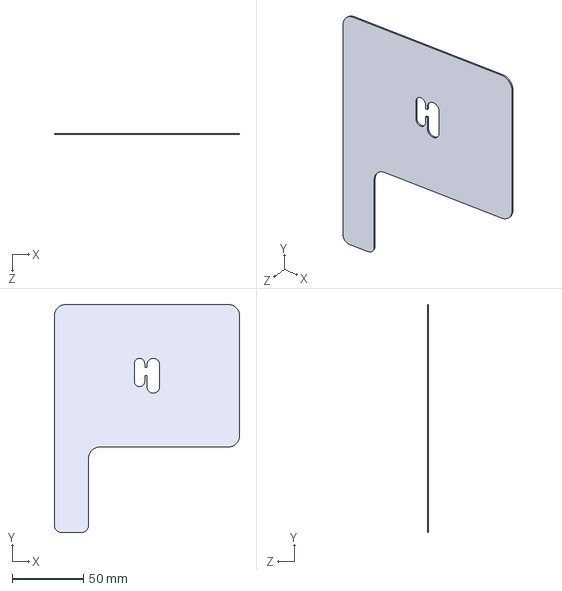
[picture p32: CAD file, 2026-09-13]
Hardware/3D Shell/STEP_STL_3MF/Steel mesh soldering helper.STEP
130.0 x 160.0 x 1.00 mm

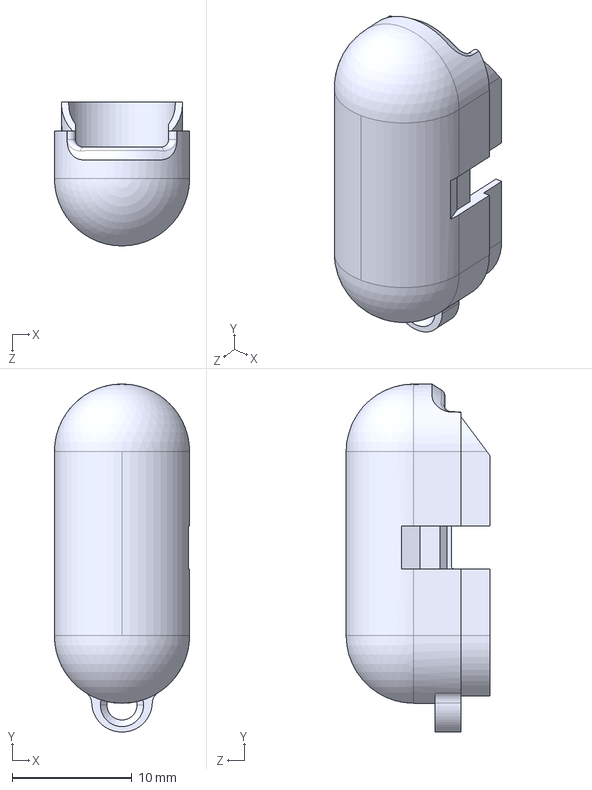
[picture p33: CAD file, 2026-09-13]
Hardware/3D Shell/STEP_STL_3MF/000#/Shell 000#_Male.STEP
11.3 x 29.1 x 12.0 mm

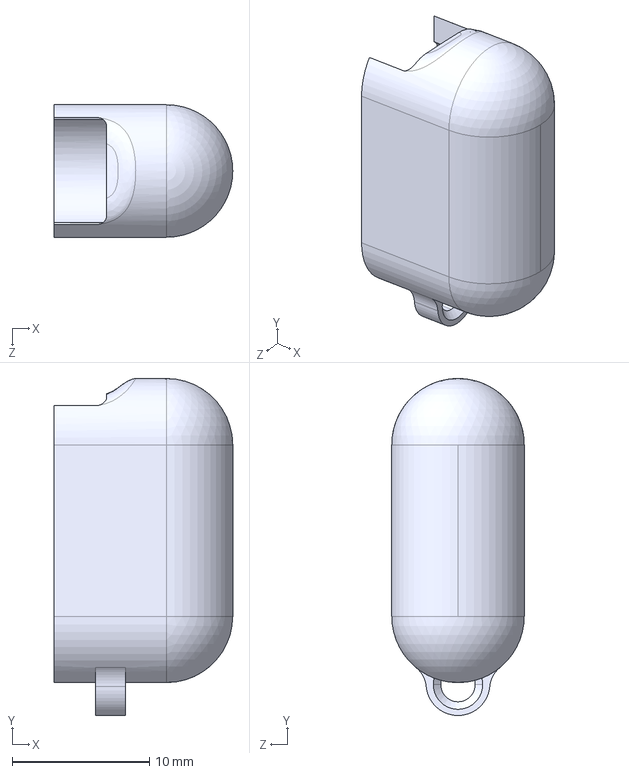
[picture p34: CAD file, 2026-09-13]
Hardware/3D Shell/STEP_STL_3MF/1#/Shell 1#_Female.STEP
13.0 x 24.6 x 9.67 mm

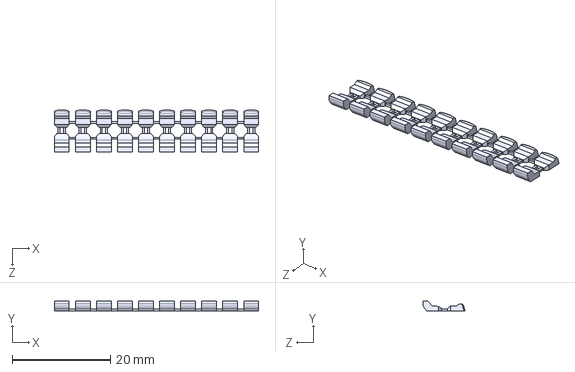
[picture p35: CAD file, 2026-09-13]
Hardware/3D Shell/STEP_STL_3MF/BTN4manufacture.STEP
41.6 x 2.00 x 8.62 mm

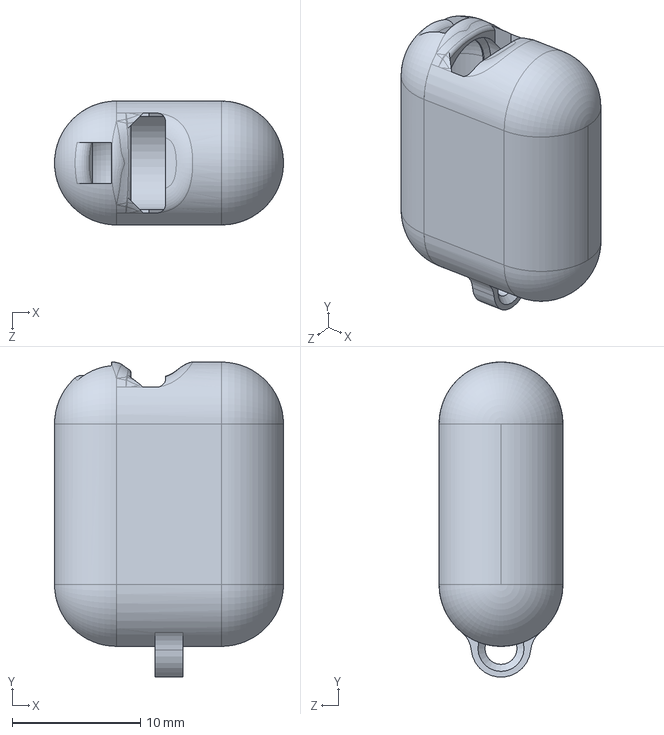
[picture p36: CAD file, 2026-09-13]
Hardware/3D Shell/SW/1#/PixPill Shell 1#.SLDPRT
17.9 x 24.6 x 9.67 mm

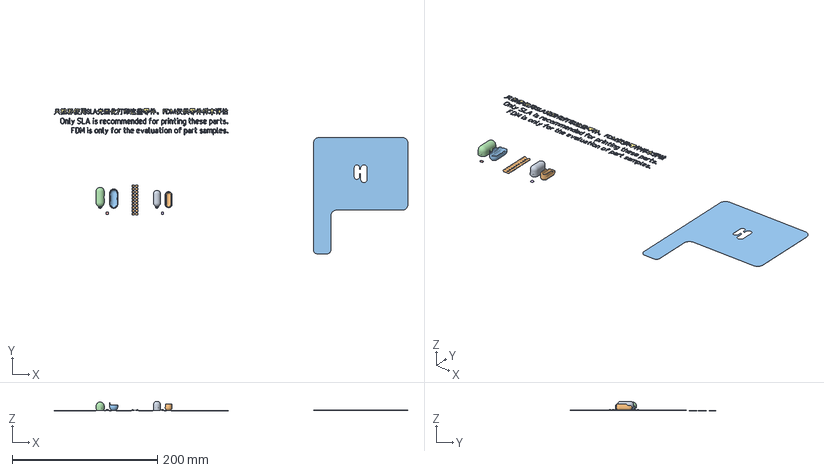
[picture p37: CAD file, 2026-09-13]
Hardware/3D Shell/STEP_STL_3MF/PixPill.3mf
486.6 x 200.1 x 13.0 mm
Shell 1#_Female.STEP
Shell 1#_Male.STEP
Shell 000#_Female.STEP
Shell 000#_Male.STEP
BTN Attacher 000#.STEP
BTN Attacher 1#.STEP
Text x 3
BTN4manufacture.STEP
Steel mesh soldering helper.STEP

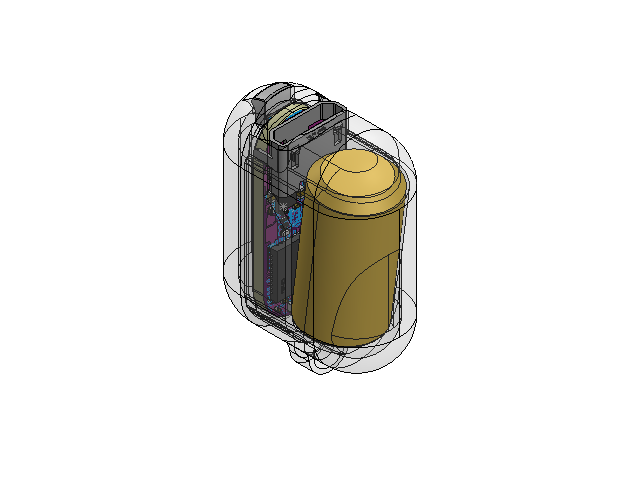
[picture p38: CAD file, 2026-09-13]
Hardware/3D Shell/SW/1#/PixPill 1#.SLDASM
PixPill Shell 1#
TopCopper~Y6nK-0.step
TopCopper~Y6nK-1.step
TopCopper~Y6nK-2.step
TopCopper~Y6nK-3.step
TopCopper~Y6nK-4.step
TopCopper~Y6nK-5.step
TopCopper~Y6nK-6.step
TopCopper~Y6nK-7.step
TopCopper~Y6nK-8.step
TopCopper~Y6nK-9.step
TopCopper~Y6nK-10.step
TopCopper~Y6nK-11.step
TopCopper~Y6nK-12.step
TopCopper~Y6nK-13.step
TopCopper~Y6nK-14.step
TopCopper~Y6nK-15.step
TopCopper~Y6nK-16.step
TopCopper~Y6nK-17.step
TopCopper~Y6nK-18.step
TopCopper~Y6nK-19.step
TopCopper~Y6nK-20.step
TopCopper~Y6nK-21.step
TopCopper~Y6nK-22.step
TopCopper~Y6nK-23.step
TopCopper~Y6nK-24.step
TopCopper~Y6nK-25.step
TopCopper~Y6nK-26.step
TopCopper~Y6nK-27.step
TopCopper~Y6nK-28.step
TopCopper~Y6nK-29.step
TopCopper~Y6nK-30.step
TopCopper~Y6nK-31.step
TopCopper~Y6nK-32.step
TopCopper~Y6nK-33.step
TopCopper~Y6nK-34.step
TopCopper~Y6nK-35.step
TopCopper~Y6nK-36.step
TopCopper~Y6nK-37.step
TopCopper~Y6nK-38.step
TopCopper~Y6nK-39.step
TopCopper~Y6nK-40.step
TopCopper~Y6nK-41.step
TopCopper~Y6nK-42.step
TopCopper~Y6nK-43.step
TopCopper~Y6nK-44.step
TopCopper~Y6nK-45.step
TopCopper~Y6nK-46.step
TopCopper~Y6nK-47.step
TopCopper~Y6nK-48.step
TopCopper~Y6nK-49.step
TopCopper~Y6nK-50.step
TopCopper~Y6nK-51.step
TopCopper~Y6nK-52.step
TopCopper~Y6nK-53.step
TopCopper~Y6nK-54.step
TopCopper~Y6nK-55.step
TopCopper~Y6nK-56.step
TopCopper~Y6nK-57.step
TopCopper~Y6nK-58.step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

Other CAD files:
Hardware/3D Shell/STEP_STL_3MF/1#/BTN Attacher 1#.STEP
Hardware/3D Shell/SW/000#/PixPill BTN Attacher 000#.SLDPRT
Hardware/3D Shell/SW/Steel mesh soldering helper.SLDPRT
Hardware/3D Shell/SW/EBA_Reference.SLDPRT
Hardware/3D Shell/STEP_STL_3MF/000#/Shell 000#_Female.stl
Hardware/3D Shell/SW/1#/PixPill BTN Attacher 1# recessing tool.SLDPRT
Hardware/3D Shell/SW/1#/battery 08120 recessing tool.SLDPRT
Hardware/3D Shell/SW/BTN4manufacture.SLDPRT
Hardware/3D Shell/SW/battery 08120 REF.SLDPRT

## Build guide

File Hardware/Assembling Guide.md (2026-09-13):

# PixPill PCB & Enclosure Assembly Guide

> [ENGLISH](Assembling%20Guide.md) | [中文](Assembling%20Guide_zh-CN.md)

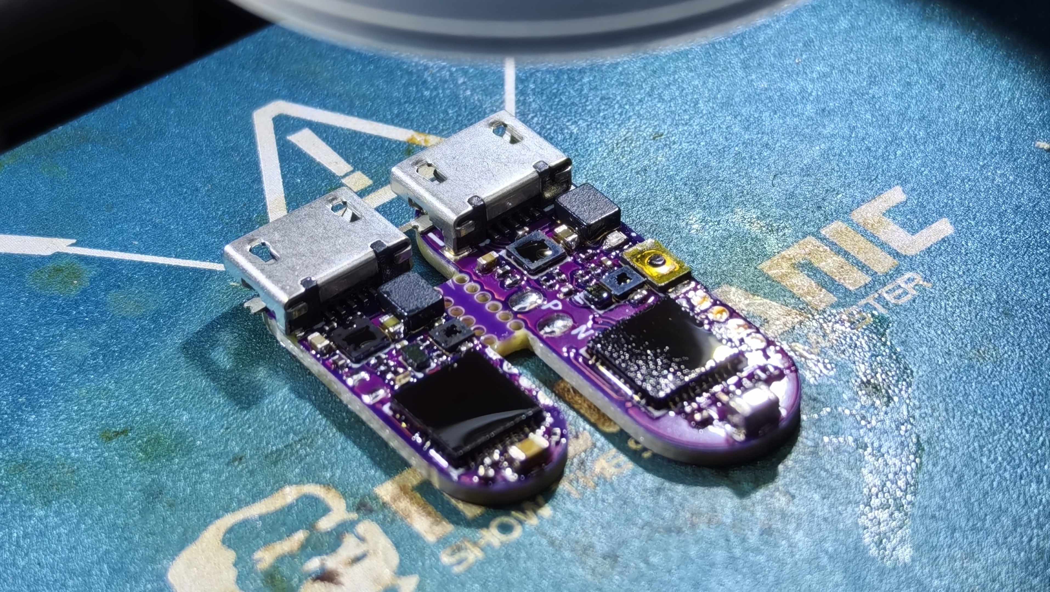
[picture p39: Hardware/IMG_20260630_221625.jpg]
PCB on heat pad


## PCB Soldering

### Required Tools and Supplies

- **Microscope**: a magnifier or microscope is required for BGA and 0201 components.
- **Soldering iron**: fine tip.
- **Hot plate and hot-air gun**: for reflowing WLCSP and BGA packages. A hot plate is recommended for the LED side; use a hot-air gun for the IC side.
- **Solder paste**: 183°C paste for the first side and 138°C low-temperature paste for the second side. A stencil is recommended for 1#.
- Flux, **fine-tip tweezers**, solder, and board-cleaning solution.

### Recommended Soldering Order

1. **Solder the LED array first**: apply solder paste, place the LEDs one by one in batches, and reflow them in batches on the hot plate.
2. After finishing the first side, turn the board over and secure it before placing the components on the second side:
   1. **SMD resistors, capacitors, and inductors (R, C, L)**
   2. **nPM1100**, **IS31FL3736**, **BMA530** (keep the package level), and **STM32C011** (hot-air soldering)
   3. **MicroUSB connector and button**
3. **Battery**: solder it with the soldering iron.

### Important Notes

- **BGA/WLCSP**: check that the solder is evenly distributed. After soldering, verify that no side is lifted and that there is no solder leakage or bridging underneath.
- **0201 LEDs**: they are extremely small and move easily. Batch soldering is strongly recommended.
- **nPM1100**: after soldering, connect USB and verify that VOUTB is approximately 3.0–3.2 V. During automatic shutdown, confirm that the 3.0 V rail drops to around 0.5 V relative to GND and continues to decrease slowly. If it remains around 3.1 V, the nPM1100 is very likely poorly soldered; rework it.
- **Battery**: always solder the battery last to avoid shorting or reversing the battery leads during assembly. Confirm the polarity carefully.

> **Warning:** WLCSP components should be used as soon as possible after purchase. Otherwise, they may absorb moisture; when heated, the moisture can expand inside the package and cause the die to crack or the component to fail.

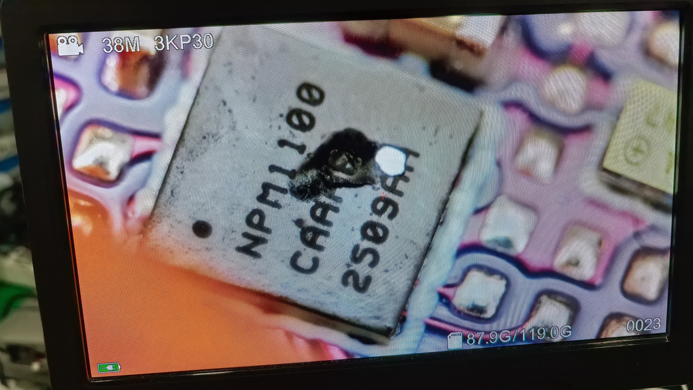
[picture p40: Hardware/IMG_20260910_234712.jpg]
WLCSP failure caused by moisture


## 3D Enclosure Assembly

1. Complete PCB soldering, flash the firmware, and verify that the board passes testing. If **the array blinks "ERR" 6 times at boot**, the IS31FL3736 has detected an LED open or short circuit; if **the LED on the IC side blinks fast while the array shows "ERR"**, it indicates an nPM1100 fault.
2. After soldering the battery, insert the PCB into the slot in the lower shell. The side with the longer battery recess corresponds to the battery slot; confirm the board orientation and position.
3. Install the button retainer in its reserved position. **First apply 502 adhesive (cyanoacrylate) or another suitable adhesive to the PCB-mounted button.** Insert the PCB into the lower shell, then insert the small button part from outside the shell and press it firmly against the PCB-mounted button.
4. Snap on the upper shell. The enclosure uses a slight interference fit.
5. Insert the microUSB cable to wake the device and verify normal operation.

### Interference-Fit Reference

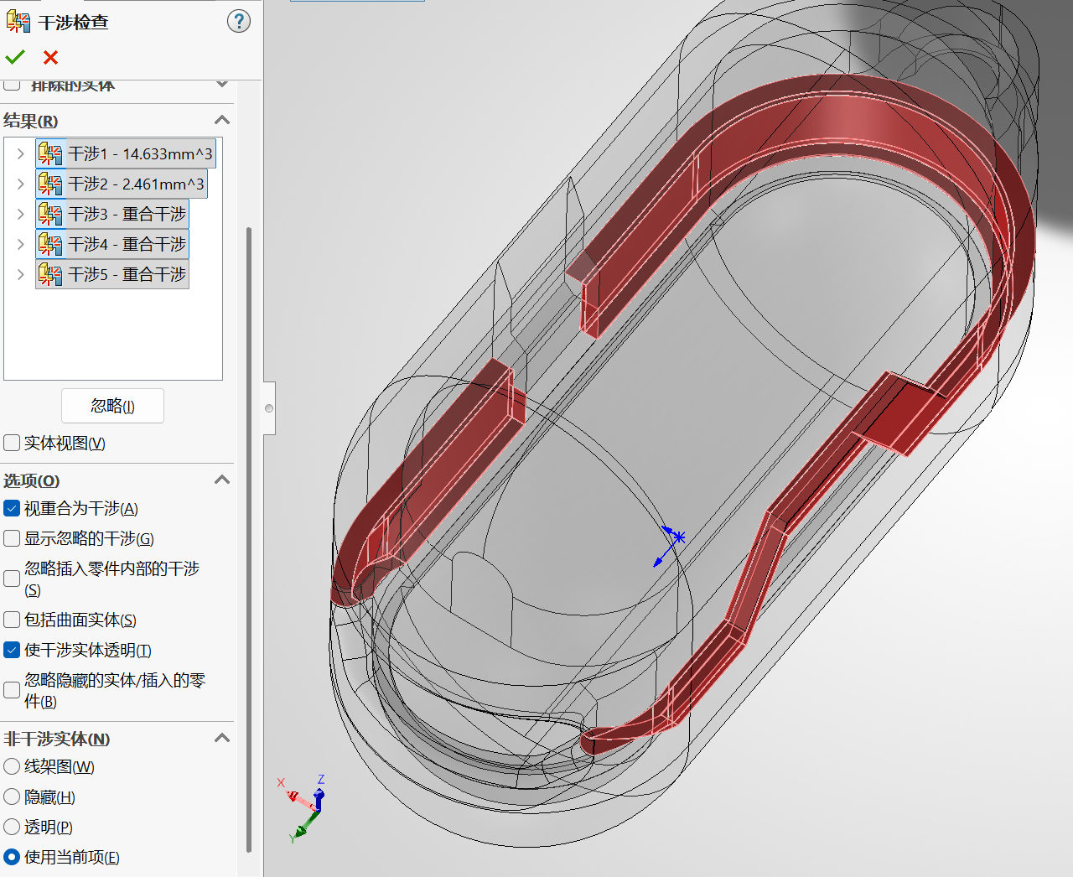
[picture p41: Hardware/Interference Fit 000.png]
Interference fit for 000#
- 000#: 
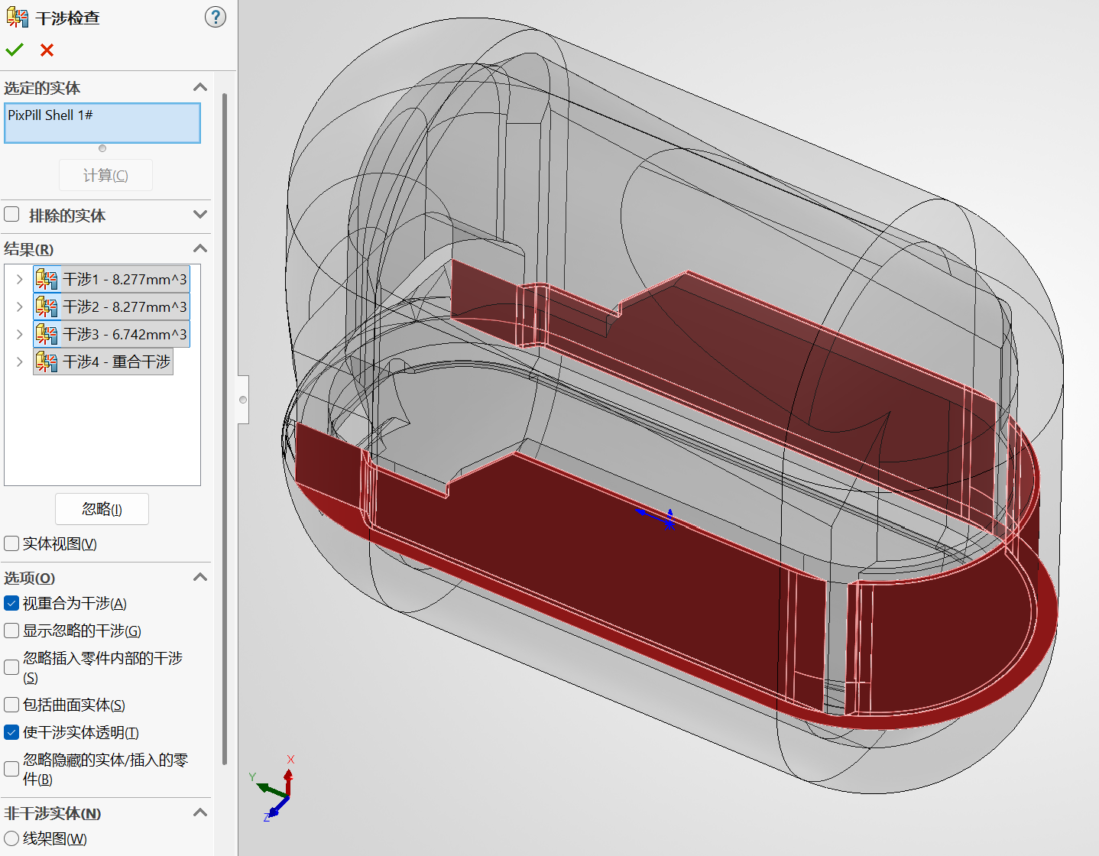
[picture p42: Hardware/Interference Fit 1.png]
Interference fit for 1#
- 1#:

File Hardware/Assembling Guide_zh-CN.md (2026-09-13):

# PixPill PCB & 外壳 组装指南

> [ENGLISH](Assembling%20Guide.md) | [中文](Assembling%20Guide_zh-CN.md)

PCB on heatpad

## PCB 焊接相关

### 工具和耗材要求

- **显微镜**：BGA 和 0201 元件必须使用放大镜或显微镜
- **烙铁**：细尖头
- **加热台&热风枪**：用于 WLCSP 和 BGA 封装回流（推荐LED面使用加热台，芯片面使用风枪）
- **锡膏**：推荐首面183℃锡膏，第二面使用138℃低温锡膏（1# 推荐开钢网）
- 助焊剂，**细尖镊**，焊锡，洗板水...

### 推荐焊接顺序

1. **先将 LED 阵列作为首面焊接**（刷好锡膏，LED逐颗分批摆好，然后批量使用加热台加热。）
2. 第一面处理好后，翻转并固定好板子，放置第二面贴片器件。
- 2.1 **SMD R、C、L**
- 2.2 **nPM1100**、**IS31FL3736**、**BMA530**（注意水平角度）、**STM32C011**（热风枪焊接）
- 2.3 **MicroUSB 座子，按钮**
3. **电池**（烙铁焊接）

### 注意事项

- BGA：WLCSP 封装注意检查植锡情况是否均匀，**焊好后必须确认是否有一边翘起或底部渗锡的不良情况**
- 0201 LED：极小，轻微移动就会移位。强烈建议分批焊接
- nPM1100：焊接完成后先接 USB，确认 VOUTB 输出约 3.0~3.2V，再确认自动关机时3.0V对地是否降到0.5V左右且持续慢慢降低，**如果维持3.1V左右，则极大概率是nPM1100虚焊**，请重新焊接。
- 电池：务必最后焊接电池，避免焊接过程中电池线短路或反接。请确认极性正确

> **警告：WLCSP 封装芯片请务必购买后尽快使用，否则芯片可能受潮，水汽会在加热时自芯片内膨胀，导致芯片穿孔报废。**

WLCSP Breaks Because of Moisture

## 3D 外壳相关

1. PCB 焊接完成、烧录固件并测试通过，若**开机时阵列闪烁6次"ERR"**，则是因为IS31FL3736 检测到 LED 开路或短路，若**芯片侧LED快闪且阵列显示"ERR"** → nPM1100 故障
2. 电池焊接后，将 PCB 插入下壳体（预留有电池槽位的相对更长的那个）的槽中确认位置和方向
3. 安装按钮固定件到壳体预留位置。**要先往PCB贴片按钮上涂敷502或其他胶水**，然后将 PCB 插入下壳体，再从壳体外插入这个小的按钮零件，和PCB贴片按钮贴合紧。
4. 扣合上壳体，壳体有轻微的过盈配合
5. 插入 microUSB 唤醒，确认运行正常

过盈配合示意：

- 000#: Interference Fit 000#
- 1#: Interference Fit 1#

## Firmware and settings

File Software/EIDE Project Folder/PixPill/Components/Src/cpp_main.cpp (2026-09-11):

/*******************************************************************************
 * @file    cpp_main.cpp
 * @version 1.1
 * 
 * @brief   PixPill firmware — application entry point and main loop.
 *
 * @details
 * PixPill is a pill-sized LED matrix gadget built around STM32C011 (WLCSP12),
 * BMA530 accelerometer, IS31FL3736 LED driver, and nPM1100 PMIC.
 *
 * The firmware simulates physical particles (sand / liquid) on a 96-LED
 * array in real time, reacting to gravity from the BMA530. A quick
 * shake gesture toggles between sand and liquid modes.
 *
 * ARCHITECTURE:
 * - Driver: `bma530` (I²C accel), `is31fl3736` (I²C LED matrix)
 * - Simulation: `SimBase` → `SandSim` (cellular automata sim) / `LiquidSim` (physically-based particle sims)
 * - Animation: `PixPillAnim` (boot / charging / error / shutdown)
 * - Power: nPM1100 ship-mode(shutdown) via SHPACT; CHG/ERR pin monitoring
 * 
 *   Memory region         Used Size  Region Size  %age Used
 *                RAM:        2872 B         6 KB     46.74%
 *              FLASH:       32676 B        32 KB     99.72%    1# Capsule
 *              FLASH:       32684 B        32 KB     99.74%    000# Capsule
 *
 * @author:     WilliTourt <willitourt@foxmail.com>
 * @date        2026-07-10
 * 
 * @changelog:
 * - 2026-07-10: Initial version
 * - 2026-07-15: 1# LED matrix adapted, added LED fault detection
 * 
 ******************************************************************************/

#include "cpp_main.h"
#include "tim.h"

#include "bma530.h"
#include "is31fl3736.h"

#include "sim_base.h"
#include "sandsim.h"
#include "liquidsim.h"
#include "pixpill_anim.h"

// ===================== State Machine =====================

enum class DeviceState : uint8_t {
    RUNNING,   // Simulation active
    SHUTDOWN   // Ship mode / stop
};

// enum class SimMode : uint8_t {
//     SAND,
//     LIQUID
// };

struct PwrFlags {
    bool charging; // USB plugged
    bool error;    // nPM fault
};

// ===================== Globals =====================

DeviceState state = DeviceState::RUNNING;
PwrFlags pwrFlags = {false, false};

BMA530 accel(&hi2c1);
IS31FL3736 is31(&hi2c1);

SimBase *sim = nullptr;
SandSim sand(accel, is31, 32);
LiquidSim liquid(accel, is31, 16);
PixPillAnim anim(is31);

// ===================== Gesture Detection =====================
// Detect a quick up-down-up-down shake (4 direction changes in SHAKE_WINDOW_MS)

static const int16_t SHAKE_THRESHOLD = 10000;   // raw accel value to count as direction change
static const uint32_t SHAKE_WINDOW_MS = 620;    // time window for gesture

uint8_t  shake_count = 0;
uint32_t shake_first_ms = 0;
bool     shake_positive = false;  // true = current direction is positive

static bool gestureDetect(int16_t ax) {
    uint32_t now = HAL_GetTick();

    // Detect zero-crossing with magnitude
    bool is_positive = (ax > SHAKE_THRESHOLD);
    bool is_negative = (ax < -SHAKE_THRESHOLD);

    if (!is_positive && !is_negative) return false;  // not enough tilt

    bool new_dir = is_positive;
    if (new_dir == shake_positive) return false;  // same direction, ignore

    // Direction changed
    if (shake_count == 0) {
        shake_first_ms = now;
    } else if (now - shake_first_ms > SHAKE_WINDOW_MS) {
        // Too slow, reset
        shake_count = 0;
        shake_first_ms = now;
    }

    shake_positive = new_dir;
    shake_count++;

    if (shake_count >= 8) {
        shake_count = 0;
        return true;
    }

    return false;
}

// ===================== Power Monitoring =====================

static void updatePowerFlags() {
    pwrFlags.charging = (HAL_GPIO_ReadPin(CHG_GPIO_Port, CHG_Pin) == GPIO_PIN_RESET);
    pwrFlags.error    = (HAL_GPIO_ReadPin(ERR_GPIO_Port, ERR_Pin) == GPIO_PIN_RESET);
}

// ===================== LED Status PWM Ctrl =====================

// 64-step sin² lookup for smooth breathing (~2.5s cycle at 25ms/call)
static const uint8_t BREATH_LUT[64] = {
    0,  1,  3,  8, 15, 24, 35, 48,
   63, 80, 98,118,139,161,184,208,
  232,255,255,255,255,255,255,255,
  255,255,255,255,255,255,255,255,
  255,232,208,184,161,139,118, 98,
   80, 63, 48, 35, 24, 15,  8,  3,
    1,  0,  0,  0,  0,  0,  0,  0,
    0,  0,  0,  0,  0,  0,  0,  0
};

static void breathLed() {
    static uint8_t  step = 0;
    static uint32_t last_ms = 0;
    uint32_t now = HAL_GetTick();
    if (now - last_ms < 25) return;
    last_ms = now;

    uint16_t pwm = (uint16_t)BREATH_LUT[step] * 999 / 255; // 999: ARR - 1
    __HAL_TIM_SET_COMPARE(&htim3, TIM_CHANNEL_2, pwm);
    step = (step + 1) & 63;
}

// ERR mode: fast blink
static void blinkLedFast() {
    static uint32_t led_last_toggle_ms = 0;
    static bool     led_on = false;
    uint32_t now = HAL_GetTick();
    if (now - led_last_toggle_ms >= 100) {
        led_last_toggle_ms = now;
        led_on = !led_on;
        __HAL_TIM_SET_COMPARE(&htim3, TIM_CHANNEL_2, (led_on ? 999 : 0));
    }
}

// ===================== Sleep / Shutdown =====================

static const uint32_t IDLE_TIMEOUT_MS = 22000;
static const int16_t  MOTION_DELTA_THRESHOLD = 1250;  // min accel change to count as "moving"
uint32_t last_active_ms = 0;
int16_t  prev_ax_idle = 0, prev_ay_idle = 0;  // previous accel for idle detection

static void enterSleep() {
    is31.ledOffAll();
    HAL_Delay(50);

    if (pwrFlags.charging) {
        while (pwrFlags.charging) {
            updatePowerFlags();
            breathLed();
            HAL_Delay(50);
        }

        HAL_TIM_PWM_Stop(&htim3, TIM_CHANNEL_2);
    }
    // Enter ship mode (shutdown)
    HAL_GPIO_WritePin(SHPACT_GPIO_Port, SHPACT_Pin, GPIO_PIN_RESET);
    HAL_Delay(100);
    HAL_GPIO_WritePin(SHPACT_GPIO_Port, SHPACT_Pin, GPIO_PIN_SET);
    HAL_Delay(1000);

    HAL_SuspendTick();
    HAL_PWR_EnterSTOPMode(PWR_MAINREGULATOR_ON, PWR_STOPENTRY_WFI);
}


void cpp_main() {
    accel.begin(BMA530::ODR::_50HZ, BMA530::Range::_2G, BMA530::Power::LPM);

    is31.begin();
    is31.setPWMAll(0xFF);

    is31.ledOnAll(45);
    HAL_GPIO_WritePin(LED_STATUS_GPIO_Port, LED_STATUS_Pin, GPIO_PIN_RESET);
    HAL_Delay(500);
    is31.ledOffAll();
    HAL_GPIO_WritePin(LED_STATUS_GPIO_Port, LED_STATUS_Pin, GPIO_PIN_SET);

    // LED open/short detect — run once at boot before simulation starts
    IS31FL3736::FaultResult faults = is31.detectFaults();
    if (faults.valid) {

        // Check if any LED has open or short fault
        uint8_t open_count = 0, short_count = 0;
        for (uint8_t i = 0; i < 96; i++) {

            #ifdef PIXPILL_SIZE_1_CAPSULE
            if (i < 6) continue;
            #endif

            if (faults.open_leds[i]) open_count++;
            if (faults.short_leds[i]) short_count++;
        }

        // If fault detected, flash ERR animation briefly then continue
        if (open_count > 0 || short_count > 0) {
            is31.setGCC(25);
            anim.start(PixPillAnim::Anim::ERR);
            uint32_t err_start = HAL_GetTick();
            while (HAL_GetTick() - err_start < 3000) {
                anim.tick();
                HAL_Delay(16);
            }
            anim.stop();
        }
    }

    is31.setGCC(25);

    sand.init();
    liquid.init();
    sim = &liquid;

    // Boot animation (blocking, ~2436ms)
    anim.start(PixPillAnim::Anim::BOOT);
    while (anim.tick(58));

    last_active_ms = HAL_GetTick();

    while (1) {
        updatePowerFlags();

        // ERR takes priority — flash LED array
        if (pwrFlags.error) {
            anim.start(PixPillAnim::Anim::ERR);
            while (pwrFlags.error) {
                HAL_TIM_PWM_Start(&htim3, TIM_CHANNEL_2);
                anim.tick();
                HAL_Delay(16);
                updatePowerFlags();
                if (!pwrFlags.error) break;  // ERR cleared
                // Blink LED_STATUS too
                blinkLedFast();
            }
            HAL_TIM_PWM_Stop(&htim3, TIM_CHANNEL_2);
            anim.stop();
            // Restore from simulation after ERR clears
            sim->draw();
        }

        // Charging indicator — play anim for 4s, then resume simulation
        static bool     was_charging      = false;
        static uint32_t charge_anim_start = 0;
        static bool     charge_anim_done  = false;

        if (pwrFlags.charging && !was_charging) {
            anim.start(PixPillAnim::Anim::CHARGING);
            HAL_TIM_PWM_Start(&htim3, TIM_CHANNEL_2);
            charge_anim_start = HAL_GetTick();
            charge_anim_done  = false;
        }

        if (!pwrFlags.charging && was_charging) {
            anim.stop();
            HAL_TIM_PWM_Stop(&htim3, TIM_CHANNEL_2);
            HAL_GPIO_WritePin(LED_STATUS_GPIO_Port, LED_STATUS_Pin, GPIO_PIN_SET);
            charge_anim_done = false;
        }

        if (pwrFlags.charging && !charge_anim_done &&
            HAL_GetTick() - charge_anim_start > 4000) {
            anim.stop();
            charge_anim_done = true;
        }
        was_charging = pwrFlags.charging;

        switch (state) {
            case DeviceState::RUNNING: {
                accel.update();
                int16_t ax = accel.readAx(), ay = accel.readAy();
                uint16_t tilt = (ax > 0 ? ax : -ax) + (ay > 0 ? ay : -ay);

                // Activity detection — any accel change counts as "moving"
                int16_t dax = ax - prev_ax_idle, day = ay - prev_ay_idle;
                if ((dax > 0 ? dax : -dax) + (day > 0 ? day : -day) > MOTION_DELTA_THRESHOLD) {
                    last_active_ms = HAL_GetTick();
                }
                prev_ax_idle = ax;
                prev_ay_idle = ay;

                // Gesture → toggle mode
                if (gestureDetect(ax)) {
                    is31.ledOffAll();
                    sim = ((sim == &liquid) ? (SimBase*)&sand : (SimBase*)&liquid);
                }

                // Run simulation (or charging animation for first 4s)
                if (!pwrFlags.charging || charge_anim_done) {
                    sim->calc();
                    sim->draw();
                } else {
                    anim.tick();  // charging breathing
                }

                // Idle timeout → shutdown
                if (HAL_GetTick() - last_active_ms > IDLE_TIMEOUT_MS) {
                    state = DeviceState::SHUTDOWN;
                }

                // Sand needs speed limit, liquid runs as fast as possible
                if (sim == &sand && !pwrFlags.charging) {
                    uint16_t delay_ms = 100000 / (tilt + 500);
                    if (delay_ms > 200) delay_ms = 200;
                    if (delay_ms < 20)  delay_ms = 20;
                    HAL_Delay(delay_ms);
                }

                if (pwrFlags.charging) {
                    breathLed();
                }
                break;
            }

            case DeviceState::SHUTDOWN: {
                // Shutdown animation (blocking, ~600ms)
                anim.start(PixPillAnim::Anim::SHUTDOWN);
                while (anim.tick()) {
                    HAL_Delay(16);
                }
                enterSleep(); // Ship mode or STOP
                while (1);
                break;
            }
        }
    }
}

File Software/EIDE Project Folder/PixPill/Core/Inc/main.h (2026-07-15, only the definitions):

#define SHPACT_Pin GPIO_PIN_15
#define SHPACT_GPIO_Port GPIOC
#define ERR_Pin GPIO_PIN_8
#define ERR_GPIO_Port GPIOA
#define CHG_Pin GPIO_PIN_7
#define CHG_GPIO_Port GPIOB
#define LED_STATUS_Pin GPIO_PIN_7
#define LED_STATUS_GPIO_Port GPIOA

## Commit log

2026-05-29 fix: PWM adjustment is removed from led setter
    [is31fl3736.cpp, is31fl3736.h]
2026-05-30 Accomplished fixed gravity falling sand
    [cpp_main.cpp]
2026-05-31 added simple velocity and acceleration effect
2026-05-31 uploaded some board image
2026-06-04 Updated EVK2 schem and pcb images
2026-06-08 Added 000# and 1# HDI Board files
2026-06-08 pin config adjustment
2026-06-09 Updated gerbers
2026-07-07 liquidsim fps improved, incompressibility to be solved
    [liquidsim.h]
2026-07-10 added LED-STATUS breathing, optimized anim
2026-07-10 bma530 odr reduced for low power
2026-07-10 Fixed: PA7 GPIO AF can't use gpio funcs
    [cpp_main.cpp, pixpill_anim.cpp]
2026-07-14 uploaded 000# solidworks files and STEP files
    [BTN Attacher 000#.STEP, PixPill BTN Attacher.SLDPRT, PixPill Shell 000#.SLDPRT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]
2026-07-14 uploaded BOMs
    [BOM_000# Capsule_Schematic2.xlsx, BOM_7_19 1# Capsule_Schematic1.xlsx, BOM_EVK_V2_TestSchematic_2.xlsx]
2026-07-15 Fixed 1# capsule wall boundary
    [cpp_main.cpp, liquidsim.h, main.h]
2026-07-15 1# LED matrix adapted, added LED fault detection
2026-07-15 fixed LED fault detection
    [cpp_main.cpp, is31fl3736.cpp, liquidsim.h]
2026-07-15 uploaded solidworks size000 files
    [PixPill BTN Attacher.SLDPRT, PixPill Shell 000#.SLDPRT, battery 08120 REF.SLDPRT]
2026-07-15 added PCB Costing img
2026-07-18 updated 3D models
    [BTN Attacher 000#.3mf, PixPill BTN Attacher 000#.SLDPRT, PixPill BTN Attacher.SLDPRT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]
2026-08-11 updated 3D Shell design SW
    [PixPill 1#.SLDASM, PixPill Shell 000#.SLDPRT, PixPill Shell 1#.SLDPRT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]
2026-08-11 completed #1 shell design
    [PixPill 1#.SLDASM, PixPill BTN Attacher 1# recessing tool.SLDPRT, PixPill BTN Attacher 1#.SLDPRT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]
2026-09-11 bugfix: wrong index for open/short fault detect
    [cpp_main.cpp, is31fl3736.cpp]
2026-09-13 Uploaded full 3D files
    [3D_Embedded Board Array.step, BTN Attacher 000#.3mf, BTN Attacher 000#.STEP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]
2026-09-13 language switch added
2026-10-12 uploaded interactive bom
2026-11-08 removed interactive bom

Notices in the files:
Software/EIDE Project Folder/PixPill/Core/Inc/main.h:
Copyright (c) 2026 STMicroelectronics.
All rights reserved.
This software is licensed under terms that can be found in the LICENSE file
